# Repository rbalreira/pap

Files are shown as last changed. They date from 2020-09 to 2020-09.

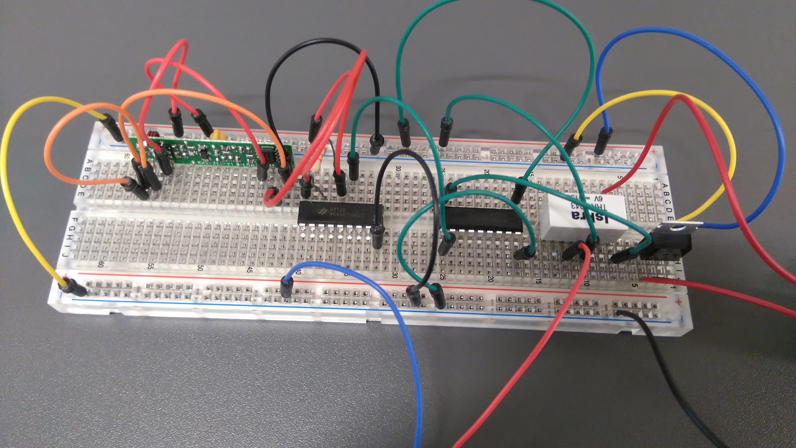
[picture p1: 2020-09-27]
assembly_pictures/receiver_14.JPG

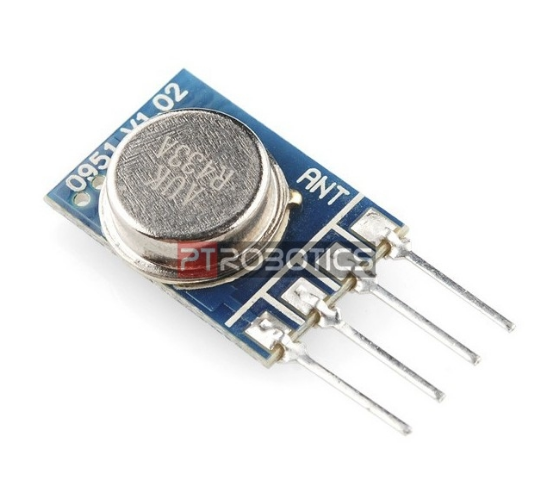
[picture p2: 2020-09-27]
components/RF transmitter.PNG

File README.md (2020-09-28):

# Prova de Aptidão Profissional
Projeto no âmbito da Prova de Aptidão Profissional do curso Técnico de Gestão de Equipamentos Informáticos do Ensino Secundário Profissional, da [Escola Secundária Marques Castilho](https://www.esmcastilho.pt/).

## Objetivo
Criação de um protótipo de pulseira electrónica conectada à campainha de uma porta de residência, permitindo que sempre que a campainha toca, um sinal é emitido para a pulseira, indicando ao portador da mesma que está alguém à porta. Com a ajuda da transmissão de radiofrequência, há ligação entre a pulseira (emissor) e a campainha (recetor). A pulseira tem um motor capaz de vibrar que indica à pessoa quando está alguém a tocar à campainha.

## Concurso Ciência na Escola
Destaque no concurso Ciência da Escola promovido pela Fundação Ilídio Pinho.

## Tecnologias
- [Fritzing](https://fritzing.org/)
- [Blender](https://www.blender.org/)

## Componentes
- RF Transmitter - 3
- RF Receiver - 2
- RF Encoder - 3
- RF Decoder - 2
- Botão de Pressão - 2
- Resistência de 750k - 4
- ULN2803 Circuito Integrado - 3
- Resistência de 33k - 4
- Motor de vibração - 3
- Buzzer - 2

## Instalação
1. Importar o projeto [assembly.fzz](assembly.fzz) no Fritzing.
2. Abrir o ficheiro [bracelet_3d.stl](bracelet_3d.stl).

## Documentação
- [Componentes usados](components)
- [Simulação do circuito](assembly.fzz)
- [Fotografias do circuito final](assembly_pictures)
- [Desenho 3D da pulseira](bracelet_3d.stl)
- [Concurso Ciência na Escola](Ciencia_na_Escola_Project/report.pdf)
- [Relatório](report.pdf)

## Autores
- Andriy Horshynskyy
- Ricardo Balreira

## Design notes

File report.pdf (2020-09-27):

IMSQUA00805

## Escola Secundária Marques de Castilho

## Técnico de Gestão de Equipamentos Informáticos

# BraceletMe

## Ricardo Balreira

## Águeda, 2017

IMSQUA00805 | i

### Índice

IMSQUA00805 | Página ii

### Índice de figuras

Fig. 3 - Placa USB (esquerda), Placa RGB LED/Botão (centro), Placa Principal

IMSQUA00805 | Página iii

IMSQUA00805 | Página iv

### Índice de quadros

IMSQUA00805 | Página v

### Resumo

Este trabalho visa explorar mecanismos que permitem a transmissão de

sinal de radiofrequência, possibilitando a interação entre uma campainha (emissor)

e uma pulseira (recetor), com recurso ao processo de comunicação com ondas de

radiofrequência, que reúne um conjunto de características ideais para o

funcionamento do mecanismo e por outro lado permite a comunicação a grandes

distâncias.

O projeto “BraceletMe” consiste na criação de um protótipo de pulseira

electrónica conectada à campainha de uma porta de residência, permitindo que

sempre que a campainha toca, um sinal é emitido para a pulseira, indicando ao

portador da pulseira que está alguém à porta. Com ajuda da transmissão de

radiofrequência vai ser possível criar uma ligação entre a pulseira (emissor) e a

campainha (recetor). A pulseira tem um motor capaz de vibrar que indica à pessoa

quando está alguém a tocar à campainha.

Palavras-chave

BraceletMe, Pulseira, Campainha, Radiofrequência.

IMSQUA00805 | 1

### 1. Introdução

No âmbito da Prova de Aptidão Profissional, foi proposto elaborar um projeto

ou atividade onde predominasse essencialmente conceitos teóricos e práticos

relacionados com a eletrónica ou com a gestão de equipamentos informáticos. A

professora responsável pela orientação do projecto foi a professora Nazaré Freitas

embora tenha sido coadjuvada pelas outras professoras da componente técnica. O

projeto teria de ser inovador, não existindo no mercado, ou introduzir qualquer

melhoria ou nova funcionalidade num produto já existente.

Apesar do constante avanço tecnológico e das diversas ideias que já foram

pensadas e postas em prática, ainda é possível dar asas à criatividade e

desenvolver um projeto inovador que surpreenda o próprio consumidor, podendo

beneficiar bastante o quotidiano do utilizador. A capacidade de poder criar algo

novo desperta a curiosidade e interesse no público e nas próprias empresas

capazes de expandir o próprio produto, o que pode ser uma mais-valia para o

criador pois vê que o seu trabalho foi reconhecido e poderá tirar grande partido da

ideia, financeiramente, pois tal como disse Flávio Souza devemos chamar o sucesso

para fazer parte [das nossas] vidas. Devemos desenvolver potencial criador, ser

inovadores, treinar a mente para vencer, estipular metas e, principalmente lutar

pelos nossos ideais.

O projeto tem como designação “BraceletMe” e foi inspirado num debate

entre algumas pessoas amigas, em que se discutiam problemas relacionados com

mobilidade nos passeios de carrinhos de bebés e pessoas portadoras de deficiência

motora. Este debate levou-nos a pensar que tipo de protótipo poderia ser

desenvolvido para ajudar as pessoas com limitações de mobilidade, ou outras. Por

outro lado, aprofundámos a nossa pesquisa com recurso à PORDATA, tentando

averiguar a percentagem de pessoas em Portugal portadoras de deficiência, e constatámos que em algumas regiões do país (Águeda, Albufeira, Porto, Lisboa,

Funchal…), a população com deficiência auditiva e visual cresceu significativamente

em 40 anos (1960-2001). Por isso, considerámos importante contribuir para a

qualidade de vida destas pessoas, lutando por um mundo melhor.

IMSQUA00805 | Página 2

O projeto “BraceletMe” consiste na criação de uma pulseira eletrónica que

emite vibração quando a campainha da porta de casa toca, indicando ao portador

que se encontra alguém à porta. O projeto parte da consciência de poder contribuir

para a solução de alguns problemas do quotidiano das pessoas portadoras de

deficiência auditiva e é movido por motivações solidárias. Além disso, poderá ainda

ter bastante utilidade no caso de pessoas com limitações inerentes à idade

avançada. A ideia surgiu também no facto de existir um familiar próximo com

problemas de audição, o que facilita assim a dificuldade em não conseguir ouvir o

toque da campainha.
Este relatório vai descrever o processo de conceção da pulseira. É

constituído por uma parte de desenvolvimento onde estará referido: o material

utilizado, maiores dificuldades na elaboração e pesquisa no projeto, vantagens e

desvantagens, fontes que foram utilizadas de forma a tornar o trabalho mais

credível, passos realizados, características dos componentes utilizados, entre

outros…; e por uma conclusão: onde haverá a oportunidade de referir a opinião

pessoal sobre o trabalho, adversidades surgidas e aspetos mais conseguidos.

### 2. Projeto “BraceletMe”

### 2.1. Esquema funcional do projeto “BraceletMe”

A imagem seguinte explica esquematicamente o objetivo do trabalho:

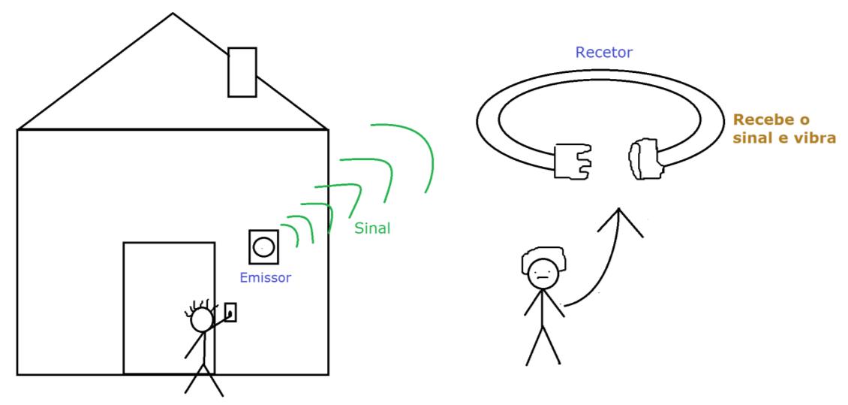
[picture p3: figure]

Fig. 1 - Esquema funcional do projeto

Como é possível observar na Fig. 1, o indivíduo que se encontra à entrada

da porta toca à campainha e, desta forma, emite um sinal para a pulseira

acionando o modo de vibração e indicando que está alguém à porta.

O projeto foi concebido para pessoas portadoras de deficiência auditiva e

para pessoas idosas, apesar de também poder ser utilizado por qualquer outro

individuo, pois também pode servir para facilitar o quotidiano de qualquer pessoa.

### 2.2. Primeira abordagem à base do projeto

Inicialmente, o protótipo a desenvolver estava em torno da utilização de um

mecanismo que permitisse a interação entre o emissor e o recetor através de

Bluetooth, o que possibilitava a transmissão de sinal sem fios. O dispositivo a ser

implementado tinha como designação de Rfduino, cuja capacidade é poder

comunicar à distância, ideal para o funcionamento do projeto. Com ótimas

características, o Rfduino pode ser alimentado por uma tensão operacional de

apenas 3V. Tem pequenas dimensões, é adaptável à pulseira e à própria campainha

e constituído por três placas (a placa principal, placa programável com entrada USB

e placa RGB LED/Botão).

São funcionalidades básicas deste dispositivo:

- Tamanho: 15 x 15 x 3.5 mm
- Tensão Operacional: 3V (Máx: 3.6V, Mín: 1.8V)
- Corrente transmitida/recebida: 8-16mA
- Processador ARM Cortex M0¹
(funcionando a 16MHz)
- 24KB de RAM
- Desenvolvido para iPhone e Android sem precisar de Xcode ou de

Android SDK (Softwares integrados para criação de aplicações)

- Bluetooth 4.0 Low Energy

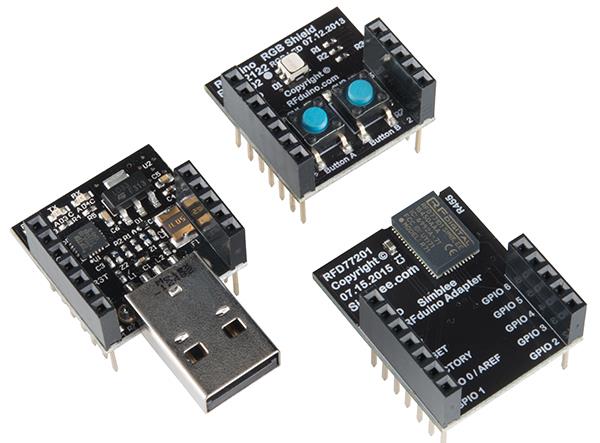
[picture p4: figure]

Fig. 2 - Equipamento Rfduino

1 Processador mais pequeno concebido pela ARM (empresa britânica de microprocessadores), com um

mínimo de requisitos de energia.

Fig. 3 - Placa USB (esquerda), Placa RGB LED/Botão (centro), Placa Principal (direita)

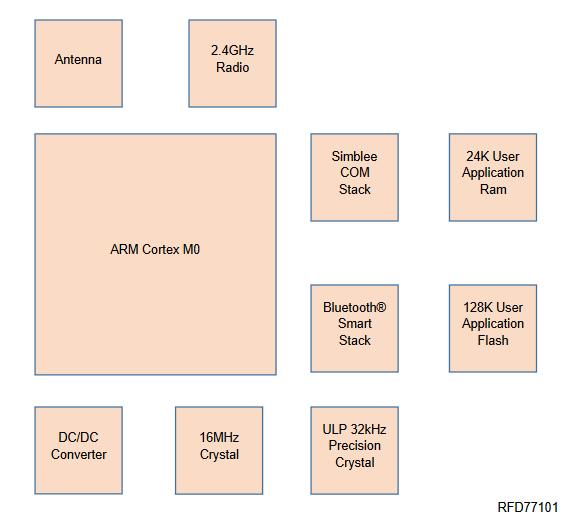
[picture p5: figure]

Fig. 4 - Diagrama de blocos, com a respetiva relação

A primeira abordagem à base do projeto consistia, portanto, em incorporar

dois microcontroladores Rfduino que pudessem comunicar entre si. Para que

houvesse a receção e passagem do sinal, teria que existir um microfone dentro do

circuito.

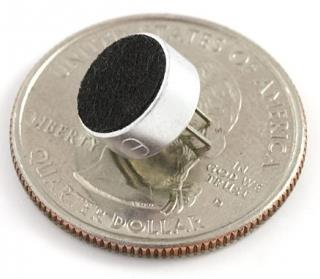
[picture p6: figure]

Fig. 5 - Microfone a ser adquirido pela Proto-Pic (loja online britânica)

No que respeita ao componente responsável por emitir sinal na pulseira, o

elemento que iria assumir essa função seria o motor de vibração.

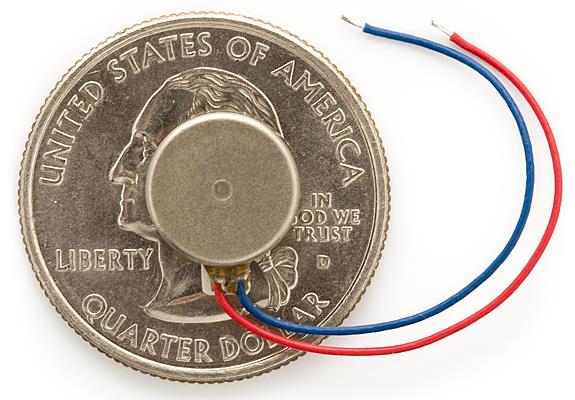
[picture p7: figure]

Fig. 6 - Motor de vibração da Sparkfun, loja online norte-americana

Depois de termos uma noção dos elementos a utilizar no projeto,

prosseguimos para a etapa seguinte, que consistia em procurar e pesquisar formas

de instalar cada componente nas condições descritas anteriormente. Através dos

esquemas elétricos de ambos os componentes e do Rfduino, procurámos conhecer

o esquema do funcionamento de uma campainha, de forma a determinar maneiras

de instalar a estrutura do Rfduino e do microfone na campainha, uma vez que o

motor de vibração irá estar na pulseira.

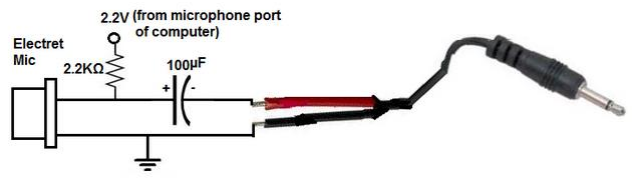
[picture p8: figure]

Fig. 7 - Circuito do microfone

Como mostra a fig. 7, para montar um microfone do tipo eletreto (cuja

finalidade é servir de escuta) vai ser preciso utilizar uma resistência de 2.2KΩ e um

condensador eletrolítico de 100µF. Como também será necessário interligar a uma

ficha de áudio e assim conectar a um computador ou a uma coluna, chegámos à

conclusão que não era, de certo modo, vantajoso optar por este elemento, dado

que este circuito exigia demasiada complexidade, segundo os tutoriais vídeo que

demonstravam, passo a passo, a montagem.

Partindo do pressuposto que a nossa “BraceletMe” estaria conectada a uma

campainha de residência (Fig. 8), estudámos o esquema elétrico respetivo.

Procedemos também ao desenho do esquema do microfone no programa “Fritzing”

para nos auxiliar na montagem do protótipo (Fig. 9). Por outro lado, pesquisámos

um esquema elétrico que possibilitasse a vibração da pulseira através de um motor

de vibração (Fig. 10) e complementámo-lo com outro esquema no programa

“Fritzing” (Fig. 11) de modo a poder recriar essa funcionalidade no protótipo.

Finalmente, a fig. 12 ilustra a junção das duas componentes: o emissor (esquema

do microfone) e o recetor (esquema do motor de vibração).

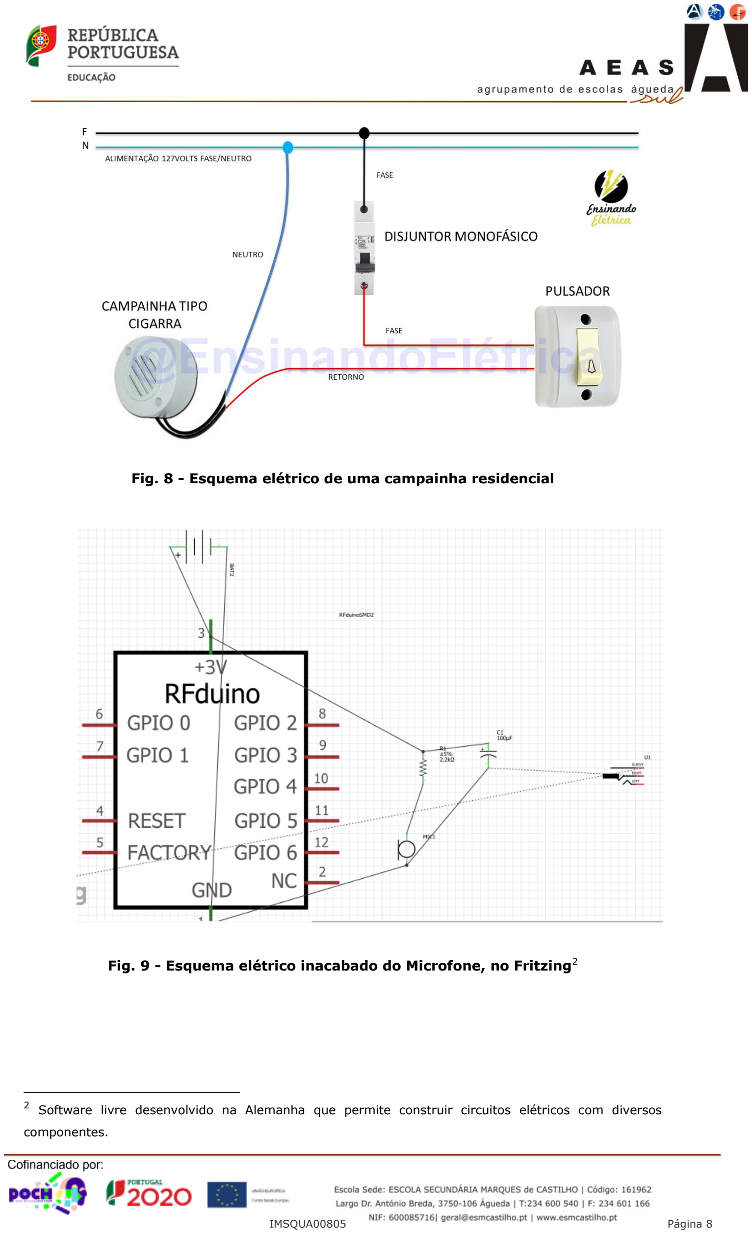
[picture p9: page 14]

Fig. 8 - Esquema elétrico de uma campainha residencial

Fig. 9 - Esquema elétrico inacabado do Microfone, no Fritzing²

2 Software livre desenvolvido na Alemanha que permite construir circuitos elétricos com diversos

componentes.

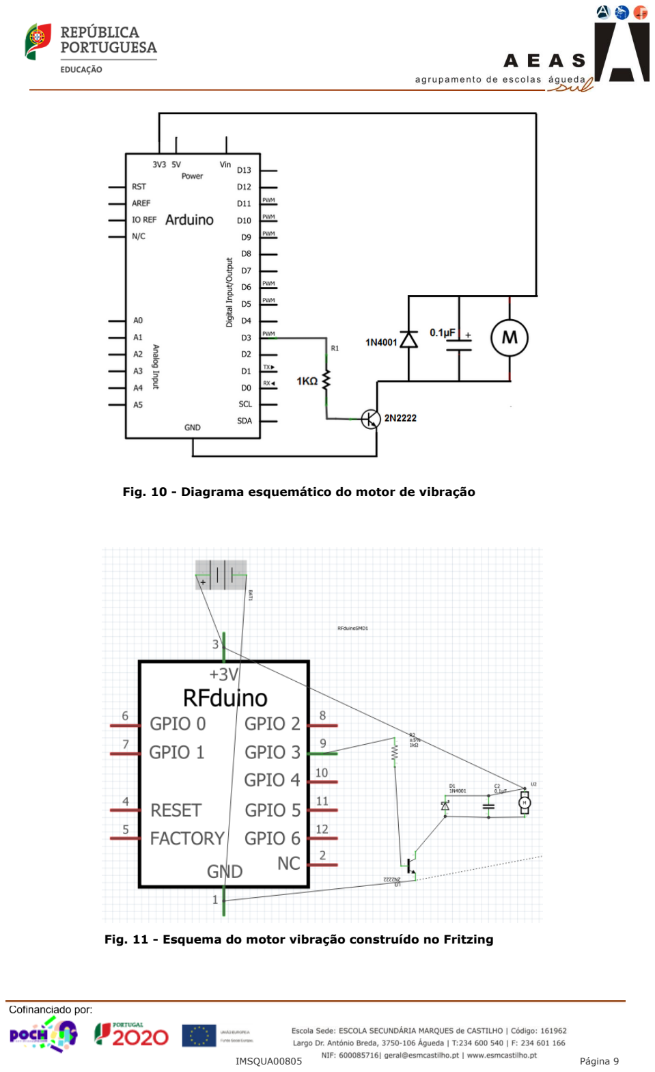
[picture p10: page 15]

Fig. 10 - Diagrama esquemático do motor de vibração

Fig. 11 - Esquema do motor vibração construído no Fritzing

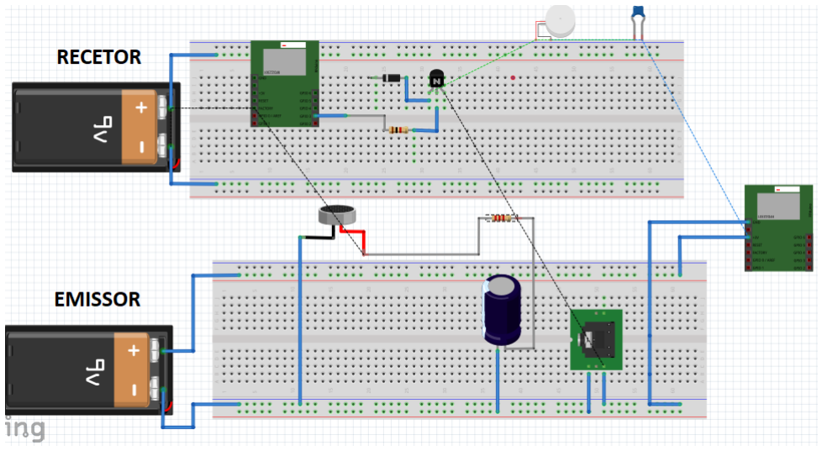
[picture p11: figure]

Fig. 12 - Esboço da primeira base do projeto montado no Fritzing

De modo a possibilitar a simulação do circuito, sem ter que recorrer a uma

campainha de uma casa, surgiu a hipótese de utilizar uma componente que

emitisse um som semelhante a uma campainha. Foi utilizado, então, um buzzer

(Fig. 14), dispositivo que envia sinal sonoro, para substituir a função da campainha.

Seguindo alguns tutoriais, operacionalizou-se a simulação, no Fritzing, do buzzer e

outros elementos necessários, como o botão de pressão, o motor de vibração, a

resistência de 330Ω, a pilha de 9V e a breadboard, tal como mostra a fig. 13.

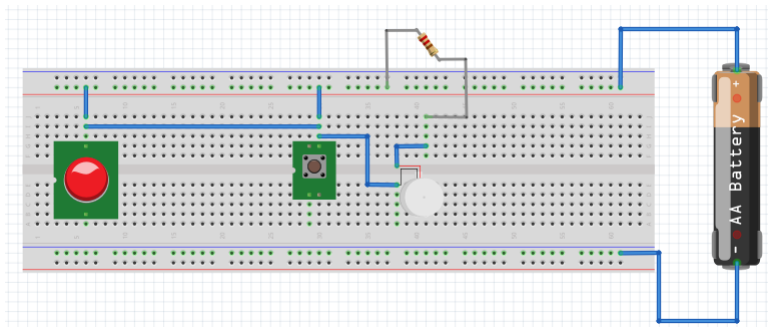
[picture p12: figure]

Fig. 13 - Simulação do motor de vibração e buzzer

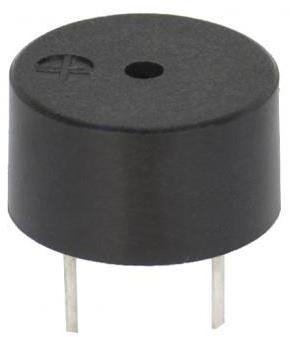
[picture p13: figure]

Fig. 14 - Exemplo de um buzzer

Na fig. 13, o buzzer está ligado ao botão de pressão e este está ligado ao

motor de vibração, com uma resistência ligada ao terminal positivo. Desta forma,

assim que é pressionado o botão de pressão, o buzzer e o motor de vibração são

ativados.

No entanto, após algumas pesquisas e discussão entre a professora

orientadora e os orientandos, inferiu-se que não era possível continuar com este

método de resolução do problema, uma vez que dois Rfduinos não conseguem

interagir um com o outro. O Rfduino foi apenas desenvolvido para comunicar com

tablet ou telemóvel (Fig. 15).

Fig. 15 - Esquema que mostra as funcionalidades do Rfduino

No fórum online do Rfduino, onde diversas pessoas podem esclarecer

dúvidas com especialistas, o administrador afirmou que não é possível interligar um

com o outro, referindo que este tipo de microcontrolador é um periférico, apenas

utilizado para dispositivos móveis que utilizam Bluetooth; no entanto, ele diz ainda

que outras funcionalidades estão a ser desenvolvidas, estando em estudo a

utilização de mecanismos de radiofrequência (emissor – recetor) – RF library – sem

ter que recorrer a via Bluetooth.

Assim, procurámos outros procedimentos e soluções para resolver esta

questão. Surgiu a ideia de utilizar o mesmo mecanismo usado nos automóveis para

o controlo remoto.

### 2.3. Nova abordagem ao esquema funcional do projeto

Decidimo-nos por uma solução bastante eficaz e simples que permite a

comunicação à distância. Essa solução consistia em utilizar um transmissor e um

recetor comunicando através de radiofrequência (RF). A imagem (Fig. 16) mostra a

fonte de onde nos inspirámos para desenvolver uma nova abordagem.

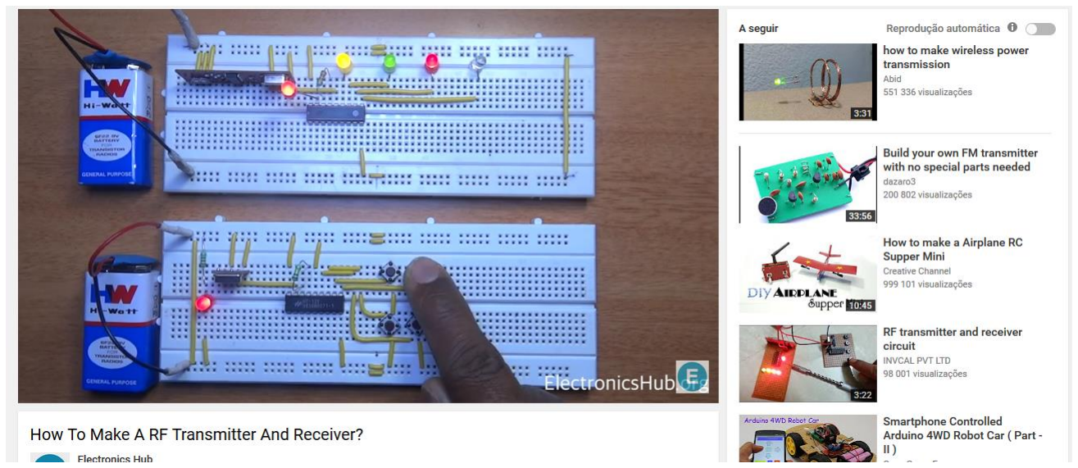
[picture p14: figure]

Fig. 16 - Vídeo que explica como utilizar um transmissor e recetor a RF

Esta técnica consiste em utilizar o módulo RF (“transmitter” e “receiver”) e

dois RF “encoder” e “decoder”, sendo os elementos principais da montagem. Cada

componente tem a sua função que passaremos a descrever:

- RF transmitter – componente eletrónico que recebe dados em série e

transmite-os, sem necessitar de conexão de fios, através da sua antena

conectada no pino 4.

- RF receiver – os dados transmitidos são recebidos por este componente

que opera à mesma frequência que o RF transmitter.

- RF encoder e decoder - utilizam-se na ligação de controlo remoto RF,

assegurando e tornando mais fiável essa mesma ligação, sendo bastante

fácil incorporá-los no RF module (módulo RF), sendo facilmente

integrados. Tal como os nomes indicam, encoder e decoder significam

“codificar” e “descodificar”, respetivamente.

Como o autor do vídeo utilizou o circuito para outra finalidade – ligar vários

díodos LED alternadamente – foi preciso estudar o circuito, cada componente e

consultando o datasheet de cada componente (ficha técnica) e a ligação dos

terminais e pinos, de forma a retirar os LED e substitui-los pelo buzzer e motor de

vibração, deixando apenas um botão de pressão no emissor.

### 2.4. Método do circuito final

Encontrada a solução para assegurar a funcionalidade do esquema do nosso

projeto, procedemos à aquisição das duas componentes essenciais: RF transmitter

e o RF receiver que passaremos a descrever em pormenor o modo de

funcionamento e de ligação.

### 2.4.1 Descrição dos componentes

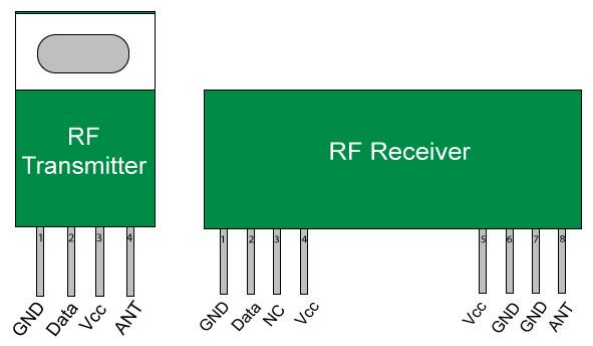
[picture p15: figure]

Fig. 17 - Identificação dos pinos do módulo RF

Nas tabelas seguintes é feita a descrição de cada pino do RF module:

Quadro 1 – RF transmitter

Número do Pino | Função | Nome
1 | Terra (0V) | GND (Terra)
2 | Pino de entrada dos dados em série | Dados
3 | Fornecedor de energia (5V) | Vcc
4 | Antena, pino de saída | ANT (Antena)

Quadro 2 – RF receiver

Número do Pino | Função | Nome
1 | Terra (0V) | GND (Terra)
2 | Pino de entrada dos dados em série | Dados
3 | Pino de saída linear (não conectado) | NC (Não Conectado)
4 | Fornecedor de energia (5V) | Vcc
5 | Fornecedor de energia (5V) | Vcc
6 | Terra (0V) | Terra
7 | Terra (0V) | Terra
8 | Antena, pino de saída | ANT (Antena)

Do RF transmitter faz parte a componente Encoder que tem as seguintes

caraterísticas:

- Tensão Operacional:
- 2.4V ~ 5V HT12A
- 2.4V ~ 12V HT12E
- Baixa Energia e Elevada Imunidade de Ruído Tecnologia CMOS³
- HT12A com um transportador de 38kHz para a transmissão de infravermelho

médio

- Mínima Transmissão de Palavra:
- Quatro Palavras (Words) HT12E
- Uma Palavra HT12A
- Oscilador integrado que necessita apenas de 5% de resistência
- O código de dados tem polaridade positiva
- Componentes Externos Mínimos
- HT12A/E: 18 pinos DIP⁴
(Dual In-Line Package) / 20 pinos SOP (Small

Outline Package)

3 CMOS – “Complementary Metal Oxide Semiconductor”. Pequena área de memória volátil, alimentada

por uma bateria.
4 Chip revestido por um plástico duro com pinos a percorrer ao longo do exterior.

O encoder pode ser aplicado em contextos vários como esclarece o quadro 3.

Quadro 3 – Aplicações do encoder

Sistema de alarme antirroubo | Sistema de alarme de incêndio e detetor de fumo
Controladores de porta de garagem | Controladores de portas de carros
Sistema carro de alarme | Sistema de segurança
Telefones sem fios | Outros sistemas de controlo remoto

O encoder obedece a um esquema específico de pinos (Fig. 18) que é

necessário ter em conta para estabelecer a ligação entre este componente e outros,

como por exemplo, botão de pressão, resistência e buzzer, tal como é ilustrado na

Fig. 27, mais à frente neste relatório.

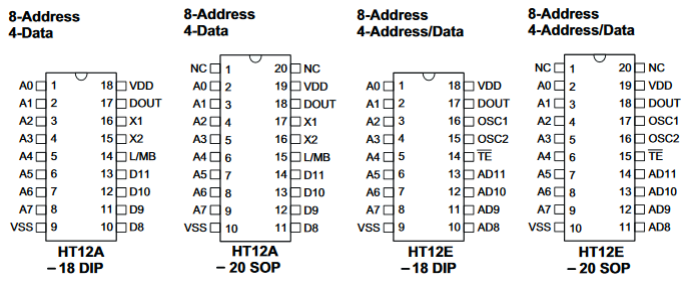
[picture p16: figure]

Fig. 18 - Esquema elétrico do RF encoder (HT12A e HT12E)

De seguida apresentamos uma tabela pormenorizada com a descrição das

características dos pinos do encoder a utilizar neste projeto.

Quadro 4 – Descrição dos pinos

Pino (designação) | I/O | Conexão Interna | Descrição
A0~A7 | I | CMOS IN Pull-High (HT12A) | Pinos de entrada para endereçarem a configuração de A0~A7. Estes pinos podem ser definidos externamente para o VSS ou podem ficar em aberto.

NMOS

Transmissão

Pino (designação) | I/O | Conexão Interna | Descrição
| | de Porta Proteção de Díodo (HT12E)
AD8~AD11 | I | NMOS Transmissão de Porta Proteção de Díodo (HT12E) | Pinos de entrada para endereçarem/dados da/a configuração de AD8~AD11. Estes pinos podem ser definidos externamente para o VSS ou podem ficar em aberto.
D8~D11 | I | CMOS IN Pull-High | Pinos de entrada para configuração e transmissão de dados de D8~D11 permitidas, baixa ativação (ver nota) Estes pinos devem ser definidos externamente para o VSS ou devem ficar em aberto
DOUT | O | CMOS OUT | Transmissão dos dados em série do codificador
L/MB | I | CMOS IN Pull-High | Transmissão do formato de seleção do pino de trinco/momentânea: Trinco: Flutuador ou VDD Momentâneo: VSS
TE | I | CMOS IN Pull-High | Permissão da transmissão, baixa ativação (ver Nota)
OSC1 | I | Oscilador 1 | Pino de entrada do oscilador
OSC2 | O | Oscilador 1 | Pino de saída do oscilador
X1 | I | Oscilador 2 | Entrada do ressonador de 455kHz no oscilador
X2 | O | Oscilador 2 | Saída do ressonador de 455kHz no oscilador
VSS | I | - | Fornecimento de energia negativa, terra
VDD | I | - | Fornecimento de energia positiva

Nota: D8~D11 são todas entradas de dados e pinos com capacidade de transmissão do HT12A. TE é um

pino com capacidade de transmissão do HT12E.

Tal | como fizemos para | o encoder, apresentamos de seguida | as

características do decoder:

- Tensão Operacional: 2.4V – 12V
- Baixa Energia e Elevada Imunidade de Ruído Tecnologia CMOS
- Capaz de descodificar 12 bits de informação
- Configuração do endereço binário
- Códigos recebidos são verificados 3 vezes

- Combinação do número de endereço/dados
- HT12D: 8 bits de endereços e 4 bits de dados
- HT12F: Apenas 12 bits de endereços
- Oscilador integrado que necessita apenas de 5% de resistência
- Indicador de transmissão válido
- Fácil Interface com um RF ou uma transmissão infravermelha média
- Componentes Externos Mínimos
- Dupla com 2¹² séries de codificadores Holtek’s⁵
- 18 Pinos DIP, 20 Pinos de pacotes SOP

Também o decoder pode ser aplicado em contextos vários como esclarece o

quadro 5.

Quadro 5 – Aplicações do decoder

Sistema de alarme antirroubo | Sistema de alarme de incêndio e detetor de fumo
Controladores de porta de garagem | Controladores de portas de carros
Sistema carro de alarme | Sistema de segurança
Telefones sem fios | Outros sistemas de controlo remoto

O decoder também obedece a um esquema específico de pinos (Fig. 19) que

é necessário ter em conta para estabelecer a ligação entre este componente e

outros, como por exemplo, motor de vibração, resistência e relé, tal como é

ilustrado na Fig. 28, mais à frente neste relatório.

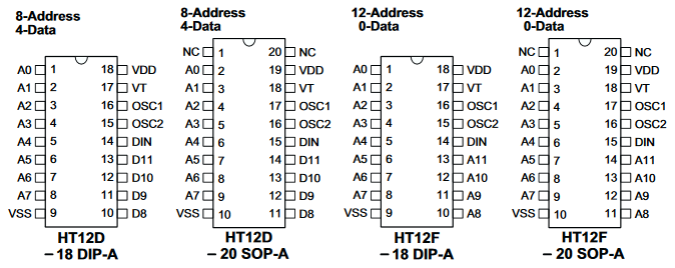
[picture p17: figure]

Fig. 19 - Esquema elétrico do RF decoder (HT12D e HT12F)

5 Empresa chinesa que produz semicondutores.

De seguida, também apresentamos uma tabela pormenorizada com a

descrição das características dos pinos do decoder a utilizar neste projeto.

Quadro 6 – Descrição dos pinos

Pino (designação) | I/O | Conexão Interna | Descrição
A0~A11 (HT12F) | I | NMOS Porta de Transmissão | Pinos de entrada para endereçarem a configuração de A0~A11 Estes pinos podem ser definidos externamente para o VSS ou podem ficar em aberto
A0~A7 (HT12D) | | | Pinos de entrada para endereçarem a configuração de A0~A7 Estes pinos podem ser definidos externamente para o VSS ou podem ficar em aberto
D8~D11 (HT12D) | O | CMOS OUT | Pino de entrada de dados, estado de energia é baixo
DIN | I | CMOS IN | Pino de entrada de dados em série
VT | O | CMOS OUT | Transmissão válida, elevada
OSC1 | I | Oscilador | Pino de entrada do oscilador
OSC2 | O | Oscilador | Pino de saída do oscilador
VSS | - | - | Fornecimento de energia negativa, terra
VDD | - | - | Fornecimento de energia positiva

A fig. 20 demonstra um dos ensaios de composição dos elementos

eletrónicos que serviria de base ao “BraceletMe”, onde se veem dois circuitos: o

transmissor, responsável por enviar o sinal para o RF receiver, está ligado ao RF

encoder que, por sua vez, está conectado ao buzzer, ao botão de pressão e à

resistência. O recetor, neste caso o RF receiver recebe o sinal vindo do RF

transmitter que está ligado ao RF decoder que estabelece a ligação com o motor de

vibração e a resistência. Assim que o RF receiver recebe o sinal o motor de vibração

é ativado.

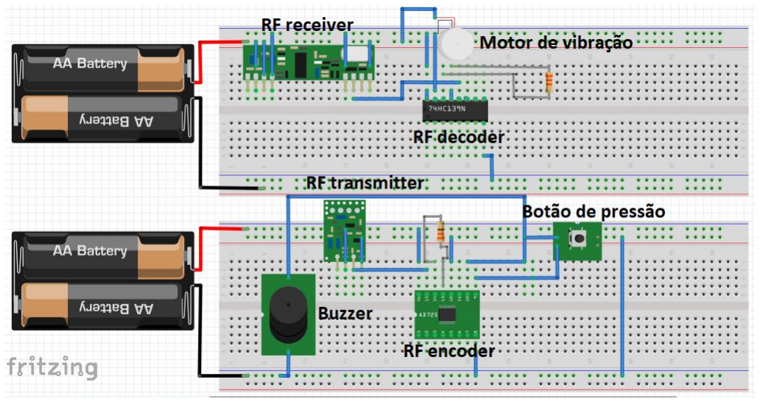
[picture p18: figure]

Fig. 20 - Esquema do método a desenvolver

Neste sistema RF, o sinal é modulado pelo que se designa por Amplitude

Shift Keying (ASK) – Deslocamento da Amplitude. Neste género de modulação, o

sinal digital sofre uma variação na sua amplitude dando origem a um sinal

analógico. Tudo isto ocorre na transmissão de ondas eletromagnéticas (Fig. 21).

Os esquemas abaixo são apenas desenhos ou esboços, pelo que servem

apenas para ver os primeiros passos na construção dos dois circuitos. No entanto,

já é possível ver como o esquema irá funcionar: o botão de pressão é pressionado e

é enviado um sinal para o RF transmitter, que depois transmite a informação para o

outro circuito, sendo recebido pelo RF receiver. O buzzer é acionado assim que

recebe corrente vindo da fonte de alimentação com a ativação do botão. Assim que

o sinal é recebido pelo RF receiver, este liga o motor de vibração (Fig. 22 - 23). O

LED do esquema do recetor foi utilizado para termos a certeza se passa ou não

corrente no circuito.

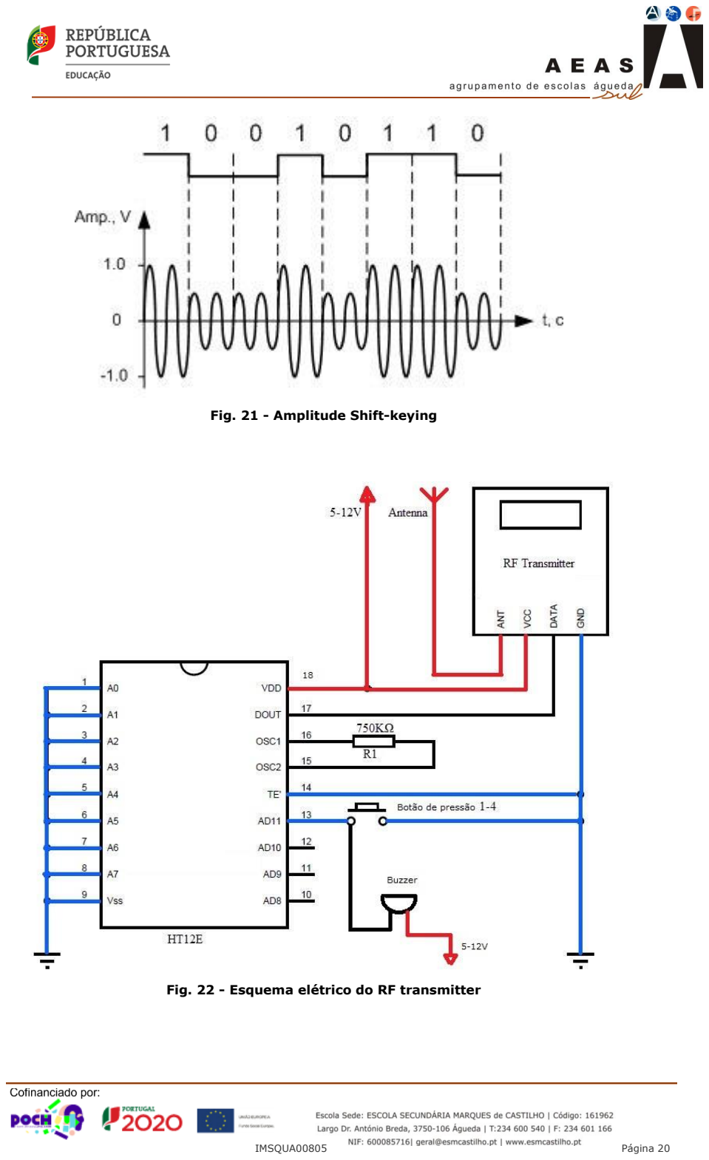
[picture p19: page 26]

Fig. 21 - Amplitude Shift-keying

Fig. 22 - Esquema elétrico do RF transmitter

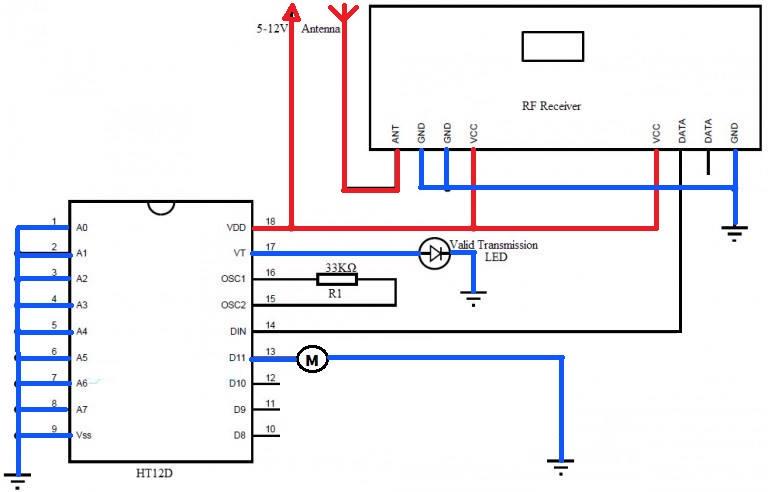
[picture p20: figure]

Fig. 23 - Esquema elétrico do RF receiver Definidos os elementos a utilizar, prosseguimos então para a etapa seguinte

que consistia em pedir o material para assim construir o protótipo. Durante o

período de montagem do circuito surgiram alguns contratempos. A ligação dos

componentes e o facto do motor de vibração estar acionado constantemente, sem

sequer existir um mecanismo que o ligasse e desligasse, foi um dos aspetos a

corrigir nesta fase.

Após a ligação entre os circuitos estar a funcionar, foi preciso optar por uma

alternativa que ligasse e desligasse o motor de vibração e buzzer consoante o

pressionar do botão de pressão. Essa alternativa consistiu em utilizar um

componente denominado de relay (relé). O relay é um componente eletromecânico

que permite ligar, desligar e comutar (desviar) um sinal, ou seja, é constituído por

um mecanismo que bloqueia, desbloqueia e muda de direção o sinal percorrido. Tal

como podemos ver na fig. 24, um relé é composto por uma bobina, uma armadura

móvel que “abre” e “fecha” e por um grupo de contactos.

Fig. 24 - Estrutura do relé

Quando essa bobina recebe corrente elétrica cria-se um campo magnético

que atua sobre a armadura, atraindo-a. Assim que essa corrente deixa de circular

pela bobina, o campo magnético desaparece fazendo com que a armadura móvel

volte à sua posição inicial. Nesta atração ocorre um movimento que ativa os

contatos, os quais podem ser abertos, fechados ou permutados, dependendo da

sua posição (Fig. 25).

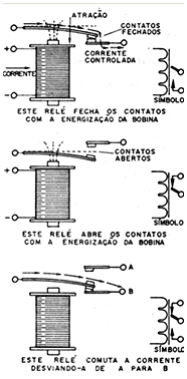
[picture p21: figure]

Fig. 25 – Funcionamento do relé

Podemos controlar circuitos de tensões bastante altas como 110V ou 120V

com um relay cuja bobina é alimentada com apenas 6V ou 12V, não

comprometendo o seu funcionamento. Consoante o seu tipo de aplicação, um relé

pode ter um ou vários contactos que podem ser designados por Normalmente

Fechado (NF), Normalmente Aberto (NA) e Contacto Comum. Os contactos podem

ter a seguinte combinação: NA, NF, NA+NF+C. Os contactos NA estão isolados

quando não existe passagem de energia; assim que há passagem de corrente, os

contactos fecham e há continuação da circulação de energia para acionar uma

carga externa (por exemplo: motor ou lâmpada). No caso dos contactos NF, a

situação é quase idêntica. A única diferença é que estes estão fechados com o relé

desativado, daí designarem-se por Normalmente Fechado. Na combinação

NA+NF+C o objetivo passa por ligar ou desligar uma das cargas quando se ativa o

relay, tendo duas cargas a alimentar. Com o relay desligado, há um contacto fechado e um segundo aberto. Quando há passagem de corrente, o relé desvia o

sinal fechando o contacto que estava aberto ficando apenas a carga 2 em

funcionamento (Fig. 26).

Fig. 26 – Funcionamento dos três tipos de relés

Para a montagem do projeto, será preciso usar um relé com quatro pinos

laterais para bloquear e desbloquear a passagem de energia. Esses quatro pinos

são formados pelos contactos NA, NF e C, tal como mostra a fig. 27. A segunda

imagem da fig. 27 é um exemplo de um tipo de relé.

Fig. 27 - Identificação dos pinos do relay a utilizar e exemplo de um relé

Imaginemos o exemplo de utilizar o motor de vibração, tal como se pretende

neste projeto. O motor de vibração está ligado ao contacto NA e, assim que ocorrer

circulação de corrente, o contacto comum desloca-se para o NA, fazendo com que o

motor receba energia e vibre.

### 2.4.2. Circuito Integrado ULN2803

No decorrer das montagens, notou-se que era preciso um microcontrolador

que permitisse conduzir a corrente até ao relé para que este ativasse e acionasse o

motor de vibração. Sem isso, não é possível a passagem de corrente até ao relé.

Neste caso foi necessário introduzir uma outra componente, circuito integrado

ULN2803, que garante a passagem de corrente (Fig. 28), onde é esquematizado os

pinos de ligação.

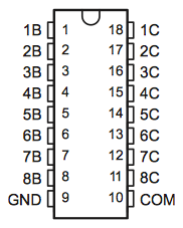
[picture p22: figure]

Fig. 28 - Identificação dos pinos do ULN2803

O quadro 7 descreve ao pormenor a tipologia e funcionalidade dos pinos do

circuito interno.

Quadro 7 – Descrição dos pinos

Pino | Tipo | Descrição
Nome | Número
1B | 1 | I | Canal 1 através da base das 8 entradas Darlington⁶
2B | 2
3B | 3

6 Transístor Darlington – é um transístor composto por dois transístores bipolares conectados onde o

segundo transístor cria uma amplificação adicional no primeiro transístor.

Pino | Tipo | Descrição
Nome | Número
4B | 4
5B | 5
6B | 6
7B | 7
8B | 8
1C | 18 | 0 | Canal 1 através do coletor das 8 saídas Darlington
2C | 17
3C | 16
4C | 15
5C | 14 | 0 | Canal 1 através do coletor das 8 saídas Darlington
6C | 13
7C | 12
8C | 11
GND | 9 | - | Emissor comum partilhado por todos os canais (típico vínculo para a terra)
COM | 10 | I/O | Nó comum do cátodo para díodos flyback (necessário para cargas indutivas)

### 2.5. Circuito Final

Introduzido o circuito ULN2803, de uma forma geral e compreensível, o

circuito global do projeto “BraceletMe” funciona da seguinte maneira:

- Assim que é pressionado o botão de pressão, é transmitida uma série de

dados onde serão verificados pelo “encoder”. Depois de este codificar a informação

recebida – com o buzzer a tocar em simultâneo – envia os dados para o RF

transmitter, e este, por sua vez, envia-os (através da sua antena) para o RF

receiver. O RF receiver envia o sinal recebido para o “decoder”, cujo papel passa

por descodificar a informação em série. Depois de esta estar devidamente

descodificada, percorre os fios condutores até ao relé, que desbloqueia logo que

esta informação é recebida. O contacto comum entra em contacto com o NA,

permitindo a circulação de corrente, o que vai possibilitar que o motor de vibração

acione, na medida em que o relé é o componente responsável por deixar percorrer

corrente até ao motor de vibração. Caso o relé não destranque, o motor de vibração não liga. Quando o botão deixa de ser pressionado, o relé volta ao ponto

inicial, isto é, fica bloqueado. Sem o circuito integrado ULN2803, não há

continuação da passagem de corrente até ao relé.

Até à fase da conclusão do circuito, foi necessário repetir várias vezes a

montagem até termos o resultado desejado, tentando corrigir os problemas de mau

contacto, falha nas ligações e falta ou excesso de passagem de corrente. Vários

problemas que surgiram ao longo do trabalho tiveram que ser analisados para

assim serem emendados. Utilizaram-se transístores para transformar a tensão da

pilha de 9V em 5V, uma vez que não tínhamos disponíveis pilhas de voltagem mais

baixa. Os transístores cingiram-se apenas para o motivo referido e para teste, em

ambos os circuitos, seguindo o seu esquema técnico de ligação (Fig. 29).

Os esquemas elétricos da fig. 30 e da fig. 31 referem-se ao circuito

concluído, com todos os elementos que foram utilizados. Concretamente, na fig. 30

(emissor), é possível ver o buzzer que está ligado ao trilho positivo da placa e ao

botão de pressão, sendo capaz de ligar e desligar o buzzer. A imagem demonstra

também o RF encoder que desempenha o papel de codificar o conjunto de dados

recebidos para depois encaminhar para o RF transmitter. A resistência de 750kΩ

opõe-se à passagem de corrente elétrica para não comprometer o funcionamento

do RF encoder. Na Fig. 30, vemos o circuito do recetor onde podemos observar o

conjunto de elementos que dele fazem parte: motor de vibração, relé, RF receiver,

RF decoder, resistência de 33kΩ e CI ULN2803. O motor de vibração está ligado ao

contacto NO (Normally Open – Normalmente Aberto) para quando o relé é acionado

possa existir passagem de energia com o contacto comum ligado ao NA. A

resistência de 33kΩ desempenha a mesma função da resistência do emissor. Para a

corrente chegar ao relé terá de passar pelo ULN2803, comprovando a sua situação

descrita anteriormente. O RF decoder recebe os dados em série do RF receiver

descodificando-os para, assim, os enviar para o ULN2803 que, por sua vez, os

transmite para o relé.

Fig. 29 - Identificação dos pinos do transístor utilizado

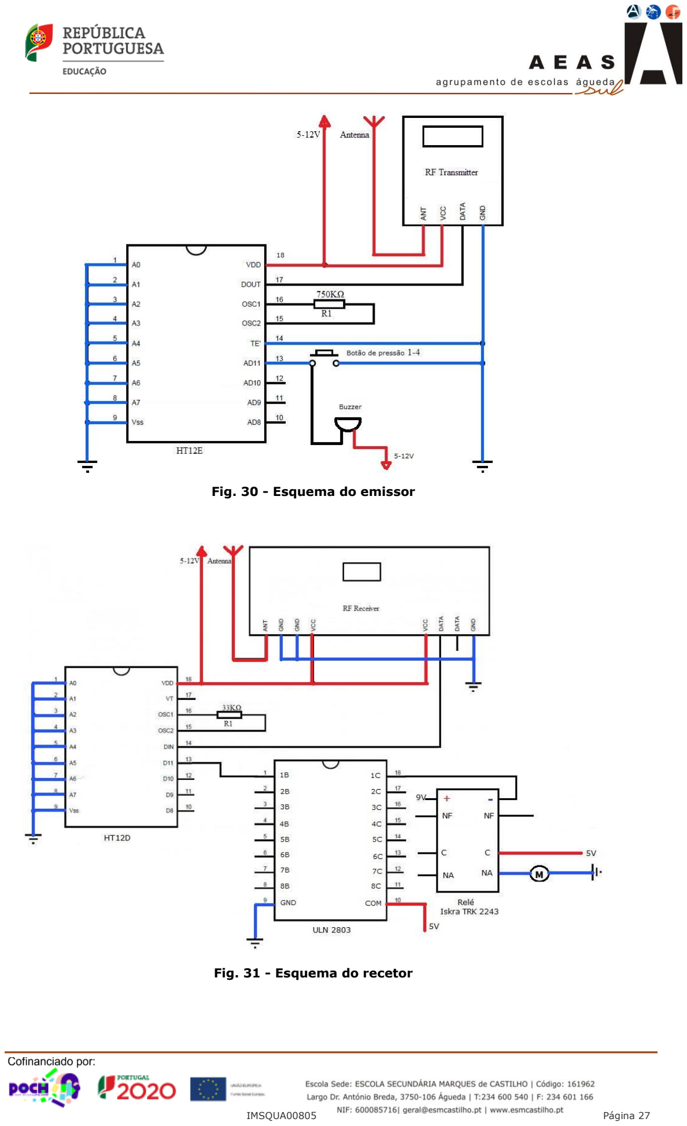
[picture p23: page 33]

Fig. 30 - Esquema do emissor

Fig. 31 - Esquema do recetor

### 2.5.1. Componentes utilizados

Os materiais utilizados na montagem do circuito foram adquiridos na

PTRobotics e na Jet7store, duas empresas portuguesas que vendem equipamento

informático. No quadro 8 estão discriminados as componentes, as suas

características e o preço de mercado. A construção do protótipo importou 55,93€.

Quadro 8 – Material Utilizado

Nome | Características | Preço
RF transmitter | ▪ Modelo PTR000875 ▪ 434 MHz ▪ 500 Metros de gama ▪ 4800bps de taxa de dados ▪ 5V tensão de alimentação | 4,61€ 3,75€ Sem IVA
RF receiver | ▪ Modelo PTR000877 ▪ 434 MHz ▪ 500 Metros de gama ▪ 4800bps de taxa de dados 5V tensão de alimentação | 5,54€ 4,50€ Sem IVA
RF encoder | ▪ Modelo PTR001199 ▪ HT12E - Codificador de controlo remoto | 3,69 € 3,00€ Sem IVA
RF decoder | ▪ Modelo PTR001199 ▪ HT12D – Descodificador de controlo remoto | 3,69 € 3,00€ Sem IVA

ULN2803 | ▪ Modelo PTR000120 | 0,80€ 0,65€ Sem IVA
2 Transístores LM7805AC | • Modelo PTR002240 • 7805 Regulador de tensão básico | 0,74€ 0,60€ Sem IVA
1 Relé | • Iskra TRK 2243 • 6V = 0136 | 2,10€ 1,71€ Sem IVA
3 Suportes de pilha 9V | - | 0,50€ 0,41€ Sem IVA

Buzzer

- Modelo PTR000607
- Resistência da bobina:

16Ω

- Corrente Máxima: 35mA
- Classificação da

Corrente: 35mA

- Diâmetro externo: 12mm
- Altura/Comprimento

externo: 8.5mm

- Frequência: 2.048kHz
- Material: PPO (Preto)
- Frequência ressonante:

2kHz

- Distância do nível do

som: 10cm

- Nível do som SPL: 85dB
- Fornecimento de tensão:

1.5V

- Fornecimento de tensão

AC Máxima: 2V

- Fornecimento de

tensão AC Mínima: 1V

- Fornecimento de

tensão Máxima: 2V

- Fornecimento de

tensão Mínima: 1V

- Peso: 1.4g

0,98 €

0,80€ Sem

IVA

Motor de vibração

- Modelo PTR002951
- Dimensões: 10mm

diâmetro, 2.7mm espessura

- Tensão: 2V – 5V
- Absorção elétrica 5V:

100mA; absorção elétrica

4V: 80mA; absorção

elétrica 3V: 60mA;

absorção elétrica 2V: 40mA

2,77€

2,25€ Sem

IVA

| ▪ 11000 Rotações p/minuto 5V ▪ Peso: 0.9 gramas
Botão de pressão | ▪ Modelo PTR001050 ▪ Botão táctil de cor preta | 0,49€ 0,40€ Sem IVA
Fios de ligação (Jumper Wires) | - | 1,85€ 1,50€ Sem IVA
2 Breadboards | - | 9,23€ 7,50€ Sem IVA
1 Resistência 33kΩ e 750kΩ | - | 0,12€ 0,10€ Sem Iva

0,29€

3 Pilhas | ▪ 9V | 2,52€ 2,05€ Sem IVA
Total (incluindo quantidade utilizada): | | 55,93€ 45,53€ Sem Iva

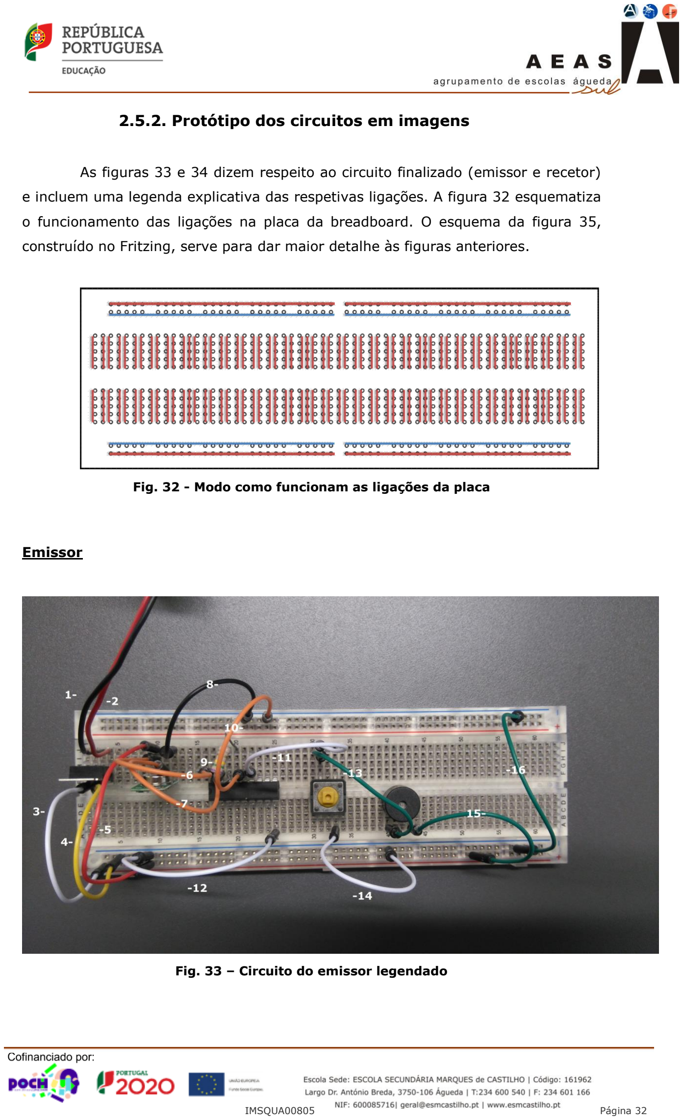
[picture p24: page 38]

### 2.5.2. Protótipo dos circuitos em imagens

As figuras 33 e 34 dizem respeito ao circuito finalizado (emissor e recetor)

e incluem uma legenda explicativa das respetivas ligações. A figura 32 esquematiza

o funcionamento das ligações na placa da breadboard. O esquema da figura 35,

construído no Fritzing, serve para dar maior detalhe às figuras anteriores.

Fig. 32 - Modo como funcionam as ligações da placa

Emissor

Fig. 33 – Circuito do emissor legendado

1 - Polo negativo da pilha (fio preto) de 9V ligado ao terminal negativo (GND) do

transístor LM7805AC.

2 - Polo positivo da pilha (fio vermelho) de 9V ligado ao terminal de entrada (Input)

do transístor LM7805AC.

3 - Fio ligado ao terminal de saída (Output) do transístor e ao trilho positivo da

breadboard.

4 - Fio ligado ao terminal Input do transístor e ao trilho negativo da breadboard.

5 - Fio que liga o pino Vcc do RF transmitter ao trilho positivo da placa breadboard.

6 - Pino Vcc do RF transmitter ligado ao pino VDD do HT12E.

7 - Pino Data do RF transmitter ligado ao pino DOUT do HT12E.

8 - Ligação do pino GND do RF transmitter ao trilho negativo da placa.

9 - Resistência de 750KΩ ligada aos pinos OSC1 e OSC2.

10 - Pino TE ligado ao trilho negativo da placa.

11 - Pino AD11 ligado a um dos terminais do botão de pressão.

12 - Pino VSS ligado ao trilho negativo da placa.

13 - Fio com ligação ao mesmo trilho do fio 11 do botão de pressão e ao terminal

negativo do buzzer.

14 - Terminal do botão de pressão ligado ao trilho negativo da placa.

15 - Ligação do terminal positivo do buzzer ao trilho positivo da placa.

16 - Interligação dos dois trilhos negativos da placa.

Recetor

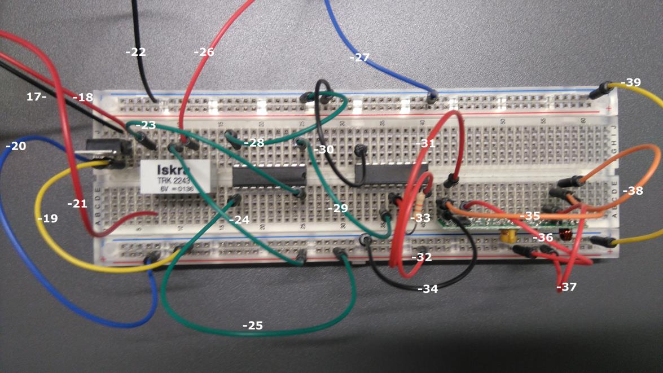
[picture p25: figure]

Fig. 34 - Circuito do recetor legendado

17 - Polo negativo da pilha de 9V ligado ao terminal negativo (GND) do transístor

LM7805AC.

18 - Polo positivo da pilha de 9V ligado ao terminal de entrada (Input) do transístor

LM7805AC.

19 - Fio ligado ao terminal GND do transístor e ao trilho negativo da breadboard.

20 - Fio ligado ao terminal Output do transístor e ao trilho positivo da placa.

21 - Ligação do polo positivo da segunda pilha ao terminal positivo do relé.

22 - Ligação do polo negativo da segunda pilha ao trilho negativo da placa.

23 - Ligação do pino 1C do ULN2803 ao terminal negativo do relé.

24 - Ligação do Contacto Comum do relé ao trilho positivo da placa (5V).

25 – Pino COM do ULN2803 está ligado ao trilho positivo da placa (5V).

26 - Ligação do terminal positivo do motor (fio vermelho) ao contacto NA do relé.

27 - Ligação do terminal negativo do motor (fio azul) ao trilho negativo da placa.

28 – Ligação do pino GND ao trilho negativo da placa.

29 - Pino 1B está ligado ao pino D11 do HT12D.

30 – Ligação do pino VSS ao trilho negativo da placa.

31 - O pino DIN do HT12D está ligado ao pino Data do RF receiver.

32 – Ligação do pino VDD ao trilho positivo da placa, ou seja, aos 5V.

33 - A resistência de 33KΩ está ligada aos pinos OSC1 e OSC2 do decoder.

34 - O pino GND do RF receiver está ligado ao trilho negativo da placa (GND).

35 – Interligação dos dois pinos GND do RF receiver.

36 – Ligação do pino VCC do RF receiver ao trilho positivo da placa breadboard.

37 – Ligação do outro pino VCC do RF receiver ao trilho positivo da placa.

38 - Interligação dos dois pinos GND do RF receiver.

39 - Interligação dos dois trilhos negativos da placa.

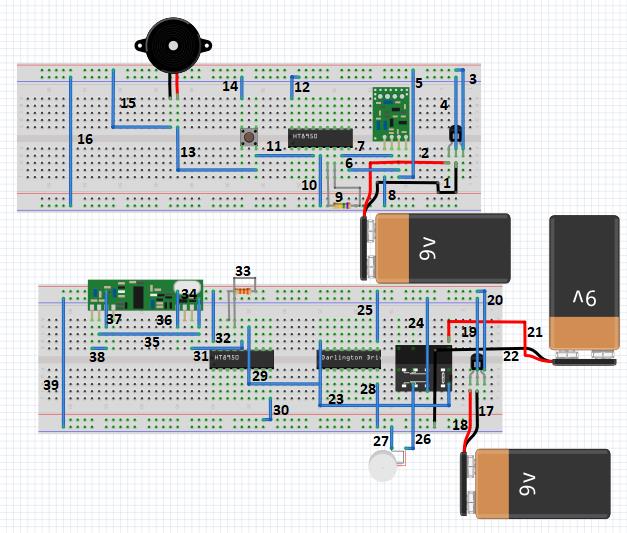
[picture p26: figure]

Fig. 35 - Esquema Fritzing com ambos os circuitos

### 3. Conclusão

Em suma, com este projeto conseguimos construir o circuito a que nos

propusemos, tendo a sua concretização correspondido às expectativas, pois foi

interessante poder criar uma pulseira recorrendo ao sistema de radiofrequência

que permite, a julgar pelos ensaios efetuados, interligar uma campainha com a

ideia de pulseira eletrónica com o objetivo de facilitar de forma simples a vida

de pessoas com dificuldades auditivas ou que, pela idade avançada, tenham

outro tipo de dificuldade sensoriais.

No âmbito teórico e prático, o projeto foi concebido com maior domínio na

área da eletrónica. Todos os elementos e conceitos usados e aplicados,

respetivamente, estiveram mais relacionados com a montagem de circuitos,

teste dos componentes, procura das fichas técnicas (datasheets), estudo da

melhor forma de realizar o projeto, e, o mais importante, com o

desenvolvimento de competências na resolução de problemas. A realização

deste tipo de trabalhos pretende procurar o lado autónomo e de autossuperação

por parte do aluno, sendo uma mais-valia para o mundo do trabalho.

Ao longo do projeto, tal como já fora referido no relatório, surgiram algumas

dificuldades, | nomeadamente | o | processo | de | testagem-erro-reformulação

permanente até ao protótipo final ficar funcional. A maior dificuldade

encontrada foi o facto de se descobrir que dois microcontroladores Rfduino não

podem ser utilizados em simultâneo porque não são compatíveis. Esta situação

afetou parcialmente o ritmo do trabalho, pois foi preciso procurar uma nova

solução rapidamente para não comprometer o desenvolvimento e a conclusão

do projeto. No entanto, o método RF Receiver e RF Transmitter provou ser mais

eficaz do ponto de vista da resistência e também uma solução mais económica

e simples. Simultaneamente os requisitos deste método viabilizaram e deram

fiabilidade ao produto. Por outro lado, aspetos como a ligação dos componentes

e a conexão correta entre o buzzer, relé e motor de vibração foram outros

pontos que precisaram de ser corrigidos.

Este projeto, para além de ter sido concebido a pensar nas pessoas

portadoras de deficiência auditiva e visual e com dificuldades inerentes à idade

avançada, pode também tirar grande proveito em pessoas que não tenham

qualquer limitação. Para além disso, esta ideia pode gerar funções novas em

oportunidades futuras, como por exemplo no caso de pessoas acamadas com

cuidadores, este sistema poderia, com os devidos ajustamentos, ser utilizado para chamar alguém que está longe, pressionando um botão e o sujeito

cuidador do outro lado recebe o sinal na pulseira. Outo exemplo poderia ser

uma pulseira com imagem e câmara exterior, ou seja, quando alguém tocasse à

campainha, essa câmara deteta a pessoa e encaminha a imagem para a

pulseira, podendo ser vista pelo portador.

O desenvolvimento destas ideias é uma mais-valia da qual a sociedade pode

tirar partido, uma vez que podem ser soluções práticas, simples e,

expectavelmente, económicas. São utilitários com impacto significativo no

quotidiano e na qualidade de vida das pessoas. E é por isso que, acreditamos,

este projeto reúne um conjunto de vantagens que podem ser usufruídas por

todas as pessoas: utilidade, simplicidade, baixo preço, fácil adaptação,

acessibilidade, durabilidade e segurança (não compromete a saúde do

utilizador, que lhe atribuem viabilidade).

### 4. Bibliografia

Baú da Eletrônica Componentes Eletrônicos Ltda. (2014). Sensor de Vibração SW-

420. Obtido de baudaeletronica:

http://www.baudaeletronica.com.br/sensor-de-vibrac-o-sw-420.html

Challenge Electronics. (2010). Omni-Directional Foil Electret Condenser Microphone.

Obtido de Sparkfun:

http://cdn.sparkfun.com/datasheets/Sensors/Sound/CEM-

C9745JAD462P2.54R.pdf

HOLTEK SEMICONDUCTOR INC. (2000). HT12A/HT12E 2^12 Series of Encoders.

Obtido de http://138.197.44.96/datasheets/HT12E.pdf

HOLTEK SEMICONDUCTOR INC. (2002). HT12D/HT12F 2^12 Series of Decoders.

Obtido de http://138.197.44.96/datasheets/HT12D.pdf

Jogando às Cegas. (2015). Jogando às cegas. Obtido de Conheça os tipos de

relógios de pulso para deficientes visuais:

http://jogandoascegas.com.br/relogios-de-pulso-para-deficientes-visuais/

Kushagra. (2012). RF Module (Transmitter & Receiver). Obtido de Engineers

Garage: https://www.engineersgarage.com/electronic-components/rf-

module-transmitter-receiver

Learning About Electronics. (s.d.). learning about electronics. Obtido de How to

Build an Elecret Microphone Circuit:

http://learningaboutelectronics.com/Articles/Electret-microphone-circuit.php

Learning About Electronics. (s.d.). learning about electronics. Obtido de How to

Build a Vibration Motor Circuit:

http://learningaboutelectronics.com/Articles/Vibration-motor-circuit.php

PORDATA. (2015). Indicadores de envelhecimento segundo os Censos - Portugal.

Obtido de Pordata:

http://www.pordata.pt/Portugal/Indicadores+de+envelhecimento+segundo

+os+Censos++-525

PORDATA. (2015). População residente com deficiência segundo os Censos: total e

por tipo de deficiência (1960-2001). Obtido de pordata:

http://www.pordata.pt/DB/Municipios/Ambiente+de+Consulta/Tabela

PRODUZA S/A. (2016). Produza. Obtido de Pré-requisitos técnicos para montar um

projeto eletrônico: http://produza.ind.br/gestao/pre-requisitos-tecnicos-

para-montar-um-projeto-eletronico/

Proto-PIC Electronic Components, RelChron Ltd. (2017). Proto Pic. Obtido de

Electret Microphone: https://www.proto-pic.co.uk/electret-microphone.html

RF Digital . (2015). Simblee™ Bluetooth® Smart Module RFD77101: DATASHEET.

Obtido de Simblee:

https://www.simblee.com/Simblee%20RFD77101%20Datasheet%20v1.0.pd

f

RFduino. (2017). Endless Possibilities For Your Projects. Obtido de Rfduino:

http://www.rfduino.com/

Robokits India. (2017). Robokits. Obtido de HT12E & HT12D Encoder And Decoder

Ic For Rf Modules: http://robokits.co.in/wireless-solutions/ht12e-ht12d-

encoder-and-decoder-ic-for-rf-modules

Santos, D. M. (2017). Relê. Obtido de Infoescola:

http://www.infoescola.com/eletronica/rele/

SparkFun Electronics. (s.d.). RFduino - Simblee Starter Kit. Obtido de Sparkfun:

https://www.sparkfun.com/products/13785

SparkFun Electronics. (s.d.). Vibration Motor. Obtido de Sparkfun:

https://www.sparkfun.com/products/8449

TechTarget. (2017). radio frequency (RF, rf). Obtido de Search Networking:

http://searchnetworking.techtarget.com/definition/radio-frequency

Texas Instruments Incorporated. (2017). ULN2803A Darlington Transistor Arrays.

Obtido de Texas Instruments:

http://www.ti.com/lit/ds/symlink/uln2803a.pdf

Usina. (s.d.). Pulseira Antiestática sem fio para proteção ESD. Obtido de Usinainfo:

http://www.usinainfo.com.br/pulseira-antiestatica/pulseira-anti-estatica-

sem-fio-para-protecao-esd-862.html

Wenshing. (s.d.). Wireless Hi Power Transmitter Module (RF ASK). Obtido de

Cloudfront:

http://dlnmh9ip6v2uc.cloudfront.net/datasheets/Wireless/General/TWS-BS-

3_433.92MHz_ASK_RF_Transmitter_Module_Data_Sheet.pdf

Wenshing. (s.d.). Wireless Hi Sensitivity Receiver Module (RF ASK). Obtido de

Cloudfront:

http://dlnmh9ip6v2uc.cloudfront.net/datasheets/Wireless/General/RWS-

371-6_433.92MHz_ASK_RF_Receiver_Module_Data_Sheet.pdf

Zhejiang Yuesui Electron Stock Co.,Ltd. (2016). Coin Type Vibration Motor . Obtido

de Sparkfun: https://cdn.sparkfun.com/datasheets/Robotics/B1034.FL45-

00-015.pdf

PTRobotics. (s.d.). Buzzer 5V. Obtido de Ptrobotics:

https://www.ptrobotics.com/som/607-buzzer-

5v.html?search_query=buzzer&results=35

PTRobotics. (s.d.). HT12D - Remote Control Decoder. Obtido de Ptrobotics:

https://www.ptrobotics.com/wireless/1200-ht12d-remote-control-

encoder.html?search_query=rf+encoder&results=3

PTRobotics. (s.d.). HT12E - Remote Control Encoder. Obtido de Ptrobotics:

https://www.ptrobotics.com/wireless/1199-ht12e-remote-control-

encoder.html?search_query=rf+encoder&results=3

PTRobotics. (s.d.). RF Link Receiver - 4800bps 434MHz. Obtido de Ptrobotics:

https://www.ptrobotics.com/wireless/877-rf-link-receiver-4800bps-

434mhz.html?search_query=rf+receiver&results=23

PTRobotics. (s.d.). RF Link Transmitter - 434MHz. Obtido de Ptrobotics:

https://www.ptrobotics.com/wireless/875-rf-link-transmitter-

434mhz.html?search_query=rf+transmitter&results=11

PTRobotics. (s.d.). Tactile Button 12mm Black. Obtido de Ptrobotics:

https://www.ptrobotics.com/tactile-switch/1050-tactile-button-12mm-

black.html?search_query=tactile+switch&results=37

PTRobotics. (s.d.). ULN2803. Obtido de Ptrobotics:

https://www.ptrobotics.com/circuitos-integrados-varios/120-

uln2803.html?search_query=uln2803&results=2

PTRobotics. (s.d.). Vibrating Mini Motor Disc. Obtido de Ptrobotics:

https://www.ptrobotics.com/motores-dc/2951-vibrating-mini-motor-

disc.html?search_query=vibration+motor&results=11

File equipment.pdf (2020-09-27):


IMSQUA00805 | Página 1
Aluno: Ricardo Balreira | 12º Ano /Turma I
Material para o projeto | Nº9
Quantidade | Nome | Modelo/referência | Link | Preço Unitário
3 | RF transmitter | PTR000875 | https://www.ptrobotics.com/wireless/875-rf-link-transmitter-434mhz.html?search_query=rf+transmitter&results=11 (https://www.ptrobotics.com/wireless/875-rf-link-transmitter-434mhz.html?search_query=rf+transmitter&results=11) | 4,61 €
3 | RF encoder | PTR001199 | https://www.ptrobotics.com/wireless/1199-ht12e-remote-control-encoder.html?search_query=rf+encoder&results=3 (https://www.ptrobotics.com/wireless/1199-ht12e-remote-control-encoder.html?search_query=rf+encoder&results=3) | 3,69 €
2 | Botão de pressão | PTR001050 | https://www.ptrobotics.com/tactile-switch/1050-tactile-button-12mm-black.html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 (https://www.ptrobotics.com/tactile-switch/1050-tactile-button-12mm-black.html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) | 0,49 €
4 | Resistência de 750k
3 | ULN2803 Circuito Integrado | PTR000120 | https://www.ptrobotics.com/circuitos-integrados-varios/120-uln2803.html | 0,80€
2 | RF receiver | PTR000877 | https://www.ptrobotics.com/wireless/877-rf-link-receiver-4800bps-434mhz.html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 (https://www.ptrobotics.com/wireless/877-rf-link-receiver-4800bps-434mhz.html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) | 5,54 €
4 | Resistência de 33k

IMSQUA00805 | Página 2
2 | RF decoder | PTR001200 | https://www.ptrobotics.com/wireless/1200-ht12d-remote-control-encoder.html?search_query=rf+decoder&results=2 (https://www.ptrobotics.com/wireless/1200-ht12d-remote-control-encoder.html?search_query=rf+decoder&results=2) | 3,69 €
3 | Motor de vibração | PTR002951 | https://www.ptrobotics.com/motores-dc/2951-vibrating-mini-motor-disc.html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 (https://www.ptrobotics.com/motores-dc/2951-vibrating-mini-motor-disc.html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) | 2,77 €
2 | Buzzer | PTR001688 | https://www.ptrobotics.com/som/1688-buzzer-12vdc.html?search_query=buzzer&results=3 6 (https://www.ptrobotics.com/som/1688-buzzer-12vdc.html?search_query=buzzer&results=36) | 3,94 €

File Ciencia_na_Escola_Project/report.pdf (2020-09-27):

Notas: Os anexos ao relatório devem ser enviados pelo correio ou entregues em mão, até ao dia 20 de maio de 2016, dirigidos à Direção de Serviços Regional /Direção Regional de Educação
a. Anexo obrigatório: uma PEN/CD/ DVD contendo uma apresentação, onde estejam bem documentadas, com imagens, as fases e produtos relevantes do projeto desenvolvido (esta apresentação complementará o relatório, na avaliação do projeto).
1. Duração máxima da apresentação: 5 minutos;
2. A PEN/CD/ DVD deverá ser identificada com o nome da Escola, o título do Projeto e o escalão.
b. Anexo(s) facultativo(s): pode(m) ser remetido(s) outro(s) documento(s) ou trabalhos finais que forem considerado(s) relevante(s) para uma boa avaliação do projeto.

RELATÓRIO FINAL DO PROJETO

1. Título do Projeto 300 carateres | BraceletMe
2. Escalão: insira o escalão 2 carateres | 5.º
3. Escola: insira o nome da escola 100 carateres | Escola Secundária Marques de Castilho

### 4. Atividades: descreva as atividades

desenvolvidas
15000 carateres

No âmbito da Prova de Aptidão Profissional, foi proposto elaborar um projeto no contexto de candidatura ao projeto Ciência na Escola da Fundação Ilídio Pinho.
O projeto “BraceletMe” consiste na criação de uma pulseira eletrónica que emite vibração quando a campainha da porta de casa toca, indicando ao portador que se encontra alguém à porta. O projeto parte da consciência de poder contribuir para a solução de alguns problemas do quotidiano das pessoas portadoras de deficiência auditiva e visual e é movido por motivações solidárias. Além disso, poderá ainda ter bastante utilidade no caso de pessoas com limitações inerentes à idade avançada. A ideia surgiu também no facto de existir um familiar próximo com problemas de audição, o que facilita assim a dificuldade em não conseguir ouvir o toque da campainha.

Foram calendarizadas as tarefas relativas à análise do projeto – processo de conceção da pulseira – procedeu-se ao desenho do projeto – pesquisa de soluções e procedimentos para a criação do projeto - e feito o levantamento dos componentes eletrónicos para o desenvolvimento do projeto.

Inicialmente, o protótipo a desenvolver estava em torno da utilização de um mecanismo que permitisse a interação entre o emissor e o recetor através de Bluetooth, o que possibilitava a transmissão de sinal sem fios. O dispositivo a ser implementado tinha como designação de Rfduino, cuja capacidade é poder comunicar à distância, ideal para o funcionamento do projeto.
A primeira abordagem à base do projeto consistia, portanto, em incorporar dois microcontroladores Rfduino que pudessem comunicar entre si. Para que houvesse a receção

Notas: Os anexos ao relatório devem ser enviados pelo correio ou entregues em mão, até ao dia 20 de maio de 2016, dirigidos à Direção de Serviços Regional /Direção Regional de Educação
a. Anexo obrigatório: uma PEN/CD/ DVD contendo uma apresentação, onde estejam bem documentadas, com imagens, as fases e produtos relevantes do projeto desenvolvido (esta apresentação complementará o relatório, na avaliação do projeto).
1. Duração máxima da apresentação: 5 minutos;
2. A PEN/CD/ DVD deverá ser identificada com o nome da Escola, o título do Projeto e o escalão.
b. Anexo(s) facultativo(s): pode(m) ser remetido(s) outro(s) documento(s) ou trabalhos finais que forem considerado(s) relevante(s) para uma boa avaliação do projeto.

RELATÓRIO FINAL DO PROJETO
e passagem do sinal, teria que existir um microfone dentro do circuito.

Prosseguimos então com a solução de utilizar dois Rfduinos fazendo vários ensaios e desenhos no programa “Fritzing” onde é possível construir circuitos elétricos. Procurámos formas de existir receção e passagem do sinal e vibração da pulseira. Consistiam, portanto, em utilizar um microfone para a receção e passagem do sinal e um motor de vibração para a pulseira emitir sinal.

No que respeita ao componente responsável por emitir sinal na pulseira, o elemento que iria assumir essa função seria o motor de vibração.
Depois de termos uma noção dos elementos a utilizar no projeto, prosseguimos para a etapa seguinte, que consistia em procurar e pesquisar formas de instalar cada componente nas condições descritas anteriormente. Através dos esquemas elétricos de ambos os componentes e do
Rfduino, | procurámos | conhecer | o | esquema | do
funcionamento de uma campainha, de forma a determinar maneiras de instalar a estrutura do Rfduino e do microfone na campainha, uma vez que o motor de vibração irá estar na pulseira.

Para montar um microfone do tipo eletreto (cuja finalidade é servir de escuta) vai ser preciso utilizar uma resistência de 2.2KΩ e um condensador eletrolítico de 100µF. Como também será necessário interligar a uma ficha de áudio e assim conectar a um computador. Chegámos à conclusão que não era, de certo modo, vantajoso optar por este elemento, dado que este circuito exigia demasiada
complexidade, | segundo | os | tutoriais | vídeo | que
demonstravam, passo a passo, a montagem.
Partindo do pressuposto que a nossa “BraceletMe” estaria conectada a uma campainha de residência, estudámos o esquema elétrico respetivo. Procedemos também ao desenho do esquema do microfone no programa “Fritzing”

Notas: Os anexos ao relatório devem ser enviados pelo correio ou entregues em mão, até ao dia 20 de maio de 2016, dirigidos à Direção de Serviços Regional /Direção Regional de Educação
a. Anexo obrigatório: uma PEN/CD/ DVD contendo uma apresentação, onde estejam bem documentadas, com imagens, as fases e produtos relevantes do projeto desenvolvido (esta apresentação complementará o relatório, na avaliação do projeto).
1. Duração máxima da apresentação: 5 minutos;
2. A PEN/CD/ DVD deverá ser identificada com o nome da Escola, o título do Projeto e o escalão.
b. Anexo(s) facultativo(s): pode(m) ser remetido(s) outro(s) documento(s) ou trabalhos finais que forem considerado(s) relevante(s) para uma boa avaliação do projeto.

RELATÓRIO FINAL DO PROJETO
para nos auxiliar na montagem do protótipo. Por outro lado, pesquisámos um esquema elétrico que possibilitasse a vibração da pulseira através de um motor de vibração e complementámo-lo com outro esquema no programa “Fritzing” de modo a poder recriar essa funcionalidade no protótipo.

De modo a possibilitar a simulação do circuito, sem ter que recorrer a uma campainha de uma casa, surgiu a hipótese de utilizar uma componente que emitisse um som semelhante a uma campainha. Foi utilizado, então, um buzzer, dispositivo que envia sinal sonoro, para substituir a
função | da | campainha. | Seguindo | alguns | tutoriais,
operacionalizou-se a simulação, no Fritzing, do buzzer e outros elementos necessários, como o botão de pressão, o motor de vibração, a resistência de 330Ω, a pilha de 9V e a protoboard.

O buzzer está ligado ao botão de pressão e este está ligado ao motor de vibração, com uma resistência ligada ao terminal positivo. Desta forma, assim que é pressionado o botão de pressão, o buzzer e o motor de vibração são ativados.
No entanto, após algumas pesquisas e discussão entre a professora orientadora e os orientandos, inferiu-se que não era possível continuar com este método de resolução do problema, uma vez que dois Rfduinos não conseguem interagir um com o outro. O Rfduino foi apenas desenvolvido para comunicar com tablet ou telemóvel.

No fórum online do Rfduino, onde diversas pessoas podem esclarecer dúvidas com especialistas, o administrador afirmou que não é possível interligar um com o outro, referindo que este tipo de microcontrolador é um periférico, apenas utilizado para dispositivos móveis que utilizam Bluetooth.

Assim, procurámos outros procedimentos e soluções para

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

RELATÓRIO FINAL DO PROJETO
resolver esta questão. Surgiu a ideia de utilizar o mesmo mecanismo usado nos automóveis para o controlo remoto.

Decidimo-nos por uma solução que permite a comunicação à distância. Essa solução consistia em utilizar um transmissor e um recetor comunicando através de radiofrequência (RF).

Esta técnica consiste em utilizar o módulo RF (“transmitter” e “receiver”) e dois RF “encoder” e “decoder”, sendo os elementos principais da montagem. O RF transmitter é uma placa de circuito impresso que recebe dados em série e transmite-os, sem necessitar de conexão de fios, através da sua antena conectada no pino 4. O RF receiver recebe os dados transmitidos por este componente que opera à mesma frequência que o RF transmitter. Os RF encoder e decoder utilizam-se na ligação de controlo remoto RF, assegurando e tornando mais fiável essa mesma ligação, sendo bastante fácil incorporá-los no RF module (módulo RF), sendo facilmente integrados. Tal como os nomes indicam, encoder e decoder significam “codificar” e “descodificar”, respetivamente. Como esta solução foi baseada num vídeo que vimos durante a pesquisa por uma nova solução, foi preciso estudar o circuito, cada componente e consultando o datasheet de cada componente (ficha técnica) e a ligação dos terminais e pinos, de forma a retirar os LED e substitui-los pelo buzzer e motor de vibração, deixando apenas um botão de pressão no emissor.

Encontrada a solução para assegurar a funcionalidade do esquema do nosso projeto, procedemos à aquisição das duas componentes essenciais: RF transmitter e o RF receiver. Os microcontroladores encoder e decoder obedecem a um esquema específico de pinos que é necessário ter em conta para estabelecer a ligação entre estes dois componente e outros, como por exemplo, botão de pressão, resistência e buzzer. Definidos os elementos a utilizar, prosseguimos então para a etapa seguinte que

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

RELATÓRIO FINAL DO PROJETO
consistia em pedir o material para assim construir o protótipo. Durante o período de montagem do circuito surgiram alguns contratempos. O facto de a ligação dos componentes e do facto do motor de vibração estar acionado constantemente, sem sequer existir um mecanismo que o ligasse e desligasse, foi um dos aspetos a corrigir nesta fase.

Após a ligação entre os circuitos estar a funcionar, foi preciso optar por uma alternativa que ligasse e desligasse o motor de vibração e buzzer consoante o pressionar do botão de pressão. Essa alternativa consistiu em utilizar um componente denominado de relé. O relé é um componente eletromecânico que permite ligar e desligar um sinal, ou seja, é constituído por um mecanismo que bloqueia e desbloqueia o sinal percorrido. Um relé é composto por uma bobina e por um grupo de contactos. Esses contactos têm
como | designação | Normalmente | Fechado | (NF) | e
Normalmente Aberto (NA), existindo um terceiro contacto (Contacto Comum) que está situado entre ambos. Quando não há passagem de energia na bobina, o contacto comum está conectado ao NF com o contacto NA aberto. Quando há passagem de corrente, a bobina cria um campo magnético que vai permitir deslocar o contacto comum ligando-se assim ao contacto NA, através de uma mola.

No decorrer das montagens, notou-se que era preciso um microcontrolador que permitisse conduzir a corrente até ao relé para que este ativasse e acionasse o motor de vibração. Sem isso, não é possível a passagem de corrente até ao relé. Neste caso foi necessário introduzir uma outra componente, circuito integrado ULN2803, que garante a passagem de corrente.

Até à fase da conclusão do circuito, foi necessário repetir várias vezes a montagem até termos o resultado desejado, tentando corrigir os problemas de mau contacto, falha nas ligações e falta ou excesso de passagem de corrente. Vários

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

RELATÓRIO FINAL DO PROJETO
problemas que surgiram ao longo do trabalho tiveram que ser analisados para assim serem emendados. Utilizaram-se transístores para transformar a tensão da pilha de 9V em 5V, uma vez que não tínhamos disponíveis pilhas de voltagem mais baixa. Os transístores cingiram-se apenas para o motivo referido e para teste, em ambos os circuitos.

### 5. Grau de experimentação do projeto:

enumere as atividades experimentais, laboratoriais ou de campo realizadas com os alunos.
4000 carateres

A primeira abordagem à base do projeto consistia, portanto, em incorporar dois microcontroladores Rfduino que pudessem comunicar entre si. Para que houvesse a receção e passagem do sinal, teria que existir um microfone dentro do circuito.

No que respeita ao componente responsável por emitir sinal na pulseira, o elemento que iria assumir essa função seria o motor de vibração.

Depois de termos uma noção dos elementos a utilizar no projeto, prosseguimos para a etapa seguinte, que consistia em procurar e pesquisar formas de instalar cada componente nas condições descritas anteriormente. Através dos esquemas elétricos de ambos os componentes e do
Rfduino, | procurámos | conhecer | o | esquema | do
funcionamento de uma campainha, de forma a determinar maneiras de instalar a estrutura do Rfduino e do microfone na campainha, uma vez que o motor de vibração irá estar na pulseira.

Para montar um microfone do tipo eletreto (cuja finalidade é servir de escuta) vai ser preciso utilizar uma resistência de 2.2KΩ e um condensador eletrolítico de 100µF. Como também será necessário interligar a uma ficha de áudio e assim conectar a um computador. Chegámos à conclusão que não era, de certo modo, vantajoso optar por este elemento, dado que este circuito exigia demasiada
complexidade, | segundo | os | tutoriais | vídeo | que
demonstravam, passo a passo, a montagem.

Partindo do pressuposto que a nossa “BraceletMe” estaria conectada a uma campainha de residência, estudámos o

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

RELATÓRIO FINAL DO PROJETO
esquema elétrico respetivo. Procedemos também ao desenho do esquema do microfone no programa “Fritzing” para nos auxiliar na montagem do protótipo. Por outro lado, pesquisámos um esquema elétrico que possibilitasse a vibração da pulseira através de um motor de vibração (Fig.
10) e complementámo-lo com outro esquema no programa “Fritzing” de modo a poder recriar essa funcionalidade no protótipo. Finalmente, a ilustra a junção das duas componentes: o emissor (esquema do microfone) e o recetor (esquema do motor de vibração).

De modo a possibilitar a simulação do circuito, sem ter que recorrer a uma campainha de uma casa, surgiu a hipótese de utilizar uma componente que emitisse um som semelhante a uma campainha. Foi utilizado, então, um buzzer, dispositivo que envia sinal sonoro, para substituir a função da campainha. Seguindo alguns tutoriais, operacionalizou-se a simulação, no Fritzing, do buzzer e outros elementos necessários, como o botão de pressão, o motor de vibração, a resistência de 330Ω, a pilha de 9V e a protoboard.

O buzzer está ligado ao botão de pressão e este está ligado ao motor de vibração, com uma resistência ligada ao terminal positivo. Desta forma, assim que é pressionado o botão de pressão, o buzzer e o motor de vibração são ativados.
No entanto, após algumas pesquisas e discussão entre a professora orientadora e os orientandos, inferiu-se que não era possível continuar com este método de resolução do problema, uma vez que dois Rfduinos não conseguem interagir um com o outro. O Rfduino foi apenas desenvolvido para comunicar com tablet ou telemóvel.

No fórum online do Rfduino, onde diversas pessoas podem esclarecer dúvidas com especialistas, o administrador afirmou que não é possível interligar um com o outro, referindo que este tipo de microcontrolador é um periférico, apenas utilizado para dispositivos móveis que utilizam Bluetooth; no entanto, ele diz ainda que essa funcionalidade

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

RELATÓRIO FINAL DO PROJETO
já está a ser desenvolvida, estando em estudo a utilização de mecanismos de radiofrequência (emissor – recetor) – RF library.
Assim, procurámos outros procedimentos e soluções para resolver esta questão. Surgiu a ideia de utilizar o mesmo mecanismo usado nos automóveis para o controlo remoto.

Decidimo-nos por uma solução bastante eficaz e simples que permite a comunicação à distância. Essa solução consistia em utilizar um transmissor e um recetor comunicando através de radiofrequência (RF).

Esta técnica consiste em utilizar o módulo RF (“transmitter” e “receiver”) e dois RF “encoder” e “decoder”, sendo os elementos principais da montagem.

Como o autor do vídeo que nos baseamos utilizou o circuito para outra finalidade – ligar vários díodos LED alternadamente – foi preciso estudar o circuito, cada componente e consultando o datasheet de cada componente (ficha técnica) e a ligação dos terminais e pinos, de forma a retirar os LED e substitui-los pelo buzzer e motor de vibração, deixando apenas um botão de pressão no emissor.

Encontrada a solução para assegurar a funcionalidade do esquema do nosso projeto, procedemos à aquisição das duas componentes essenciais: RF transmitter e o RF receiver.

Os microcontroladores encoder e decoder obedecem a um esquema específico de pinos que é necessário ter em conta para estabelecer a ligação entre este componente e outros, como por exemplo, botão de pressão, resistência e buzzer, tal como é ilustrado na, mais à frente neste relatório.

Definidos os elementos a utilizar, prosseguimos então para a etapa seguinte que consistia em pedir o material para assim construir o protótipo. Durante o período de montagem do

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

RELATÓRIO FINAL DO PROJETO
circuito surgiram alguns contratempos. O facto de a ligação dos componentes e do facto do motor de vibração estar acionado constantemente, sem sequer existir um mecanismo que o ligasse e desligasse, foi um dos aspetos a corrigir nesta fase.

Após a ligação entre os circuitos estar a funcionar, foi preciso optar por uma alternativa que ligasse e desligasse o motor de vibração e buzzer consoante o pressionar do botão de pressão. Essa alternativa consistiu em utilizar um componente denominado de relé.

No decorrer das montagens, notou-se que era preciso um microcontrolador que permitisse conduzir a corrente até ao relé para que este ativasse e acionasse o motor de vibração. Sem isso, não é possível a passagem de corrente até ao relé. Neste caso foi necessário introduzir uma outra componente, circuito integrado ULN2803, que garante a passagem de corrente, onde é esquematizado os pinos de ligação.

### 6. Relevância: indique a relevância científico-

pedagógica do projeto para os alunos e para a comunidade educativa.
3000 carateres

De um modo geral, este projeto pode ter grande relevância nos alunos pois incentiva muitos deles a dar asas à imaginação e a porem em prática as suas ideias que podem vir a ter um grande potencial. Essas ideias podem ser demasiado simples, mas se forem bem desenvolvidas podem tornar-se numa necessidade universal tirando grande proveito da sua potencialidade. Este protótipo poderá ainda ter bastante utilidade no caso de pessoas com limitações inerentes à idade avançada. De acordo com a base de dados da PORDATA, o índice de envelhecimento e de dependência de idosos aumentou progressivamente em 50 anos. À medida que uma pessoa atinge uma idade avançada, os seus sentidos (audição e/ou visão) ficam mais enfraquecidos. Desta forma, poderá ser uma grande vantagem para idosos com dificuldade em ouvir.

7. Inovação: refira aspetos inovadores, criativos ou de possível utilidade empresarial do projeto
4000 carateres

Consideramos que este projeto é inovador porque concebe um produto novo combinando componentes electrónicos já existentes e de baixo custo.
O mecanismo de protótipo resultante deste projeto pode

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

RELATÓRIO FINAL DO PROJETO
tornar-se um produto a experimentar primeiramente no seio da comunidade com dificuldade em ouvir e inerentes à idade avançada, permitindo a diminuição dos problemas do quotidiano. Deste projecto, podem surgir outras ideias semelhantes com o objectivo de facilitar o dia-a-dia do utilizador. O facto de ser simples e concebido numa necessidade básica, pode ser uma mais-valia para as empresas.

### 8. Parceria (s): indique a(s) parceria(s)

estabelecida(s) com instituições externas à escola, indicando o nome da(s) entidade(s) e o(s) contributo(s) para o
desenvolvimento do projeto.
3000 carateres

Foram estabelecidas as seguintes parcerias:
1- Águeda Living Lab (espaço aberto à comunidade para o encontro de ideias, experiências, conhecimento, criatividade e inovação de Águeda): parceiros na dinamização de um workshop usando o programa Blender onde os alunos aprenderam as noções básicas de modelação 3D, com o objetivo de desenvolver um suporte para o protótipo e posterior impressão 3D; e na disponibilização do makerspace e recursos disponíveis.

### 9. Resultados: refira os resultados obtidos

(nas aprendizagens dos alunos, na comunidade educativa e nas instituições com que estabeleceu parcerias)
3000 carateres

Este projeto insere-se na linha estratégica do Projeto Educativo Projeto Educativo AEAS 2013-17, nomeadamente nos seguintes objetivos estratégicos: aposta em modelos de ensino e aprendizagem focalizados no desenvolvimento de capacidades, assente em pedagogias diferenciadas e inovadoras que valorizem o ensino experimental das ciências e as TIC; aprofundamento e consolidação da cooperação com o tecido social e empresarial, com o poder local e com a universidade, com vista à integração plena dos alunos na vida ativa, ao desenvolvimento do gosto pela ciência, pela investigação e pela inovação e ao alargamento dos horizontes de emprego; e realização de cursos avançados, ou de aprofundamento, destinados a alunos do 9º ano e do ensino secundário e a professores, com recurso a parcerias com instituições ligadas à investigação e à promoção da educação para a ciência.
Assim, devidamente enquadrado na visão do Projeto Educativo, este projeto proporcionou aos alunos a possibilidade de desenvolverem competências ao nível do uso e aplicação de conhecimentos e metodologias para encontrarem soluções para problemas do mundo real. Além disso, os alunos promoveram a capacidade de passar das

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

RELATÓRIO FINAL DO PROJETO
ideias aos atos, através de processos de criatividade e a inovação, da assunção de riscos, bem como a capacidade de planear e gerir projetos para alcançar objetivos. Foram capazes de aproveitar esta oportunidade transformando-a em aprendizagem e desenvolvimento técnico na área das soluções pensadas informaticamente e com recurso à tecnologia eletrónica.

Além disso, desenvolveram capacidades de iniciativa na gestão de projetos e equipas; aptidão e gosto por uma aprendizagem contínua, prática na aplicação de modelos de desenho e de metodologias no âmbito de programação, experiência na realização de trabalho colaborativo; Interpretação e representação de esquemas elétricos e eletrónicos, e de identificação, medição e testagem componentes eletrónicos ….
Relativamente à comunidade educativa foram realizadas algumas apresentações no dia Aberto e nas Jornadas Técnicas da escola nos dias 3, 4 e 5 de maio, tendo despertado interesse por parte dos alunos.

Contactaram-se as empresas Feiramédica, Lenadais e Aveimédica, pertencentes ao distrito de Aveiro, ligadas à
geriatria | ou | saúde | para | poderem | contribuir | na
exequibilidade do projecto.

### 10. Informação complementar: refira outras

informações consideradas pertinentes 6000 carateres

Este projeto, para além de ter sido concebido a pensar nas pessoas portadoras de deficiência auditiva e visual e com dificuldades inerentes à idade avançada, pode também tirar grande proveito em pessoas que não tenham qualquer limitação. Para além disso, esta ideia pode gerar funções novas em oportunidades futuras, como por exemplo no caso de pessoas acamadas com cuidadores, este sistema poderia, com as devidos ajustamentos, ser utilizado para chamar alguém que está longe, pressionando um botão e o sujeito cuidador do outro lado recebe o sinal na pulseira. Outo exemplo poderia ser uma pulseira com imagem e câmara exterior, ou seja, quando alguém tocasse à campainha, essa câmara deteta a pessoa e encaminha a imagem para a

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

RELATÓRIO FINAL DO PROJETO pulseira, podendo ser vista pelo portador.

11. Lista nominal dos alunos participantes no projeto (primeiro e último nome/ano) 3000 carateres | Andriy Horshynskyy – 12.ºI Ricardo Balreira – 12.ºI
12. Lista nominal dos professores colaboradores no projeto (primeiro e último nome/grupo disciplinar) 3000 carateres | Ana Cristina Marques – Grupo 550 - Informática Nazaré Freitas – Grupo 550 - Informática Daniela Ferreira – Grupo 550 - Informática

### 13. Resumo do projeto

200 carateres

Este trabalho visa explorar mecanismos que permitem a transmissão de sinal de radiofrequência, possibilitando a interação entre uma campainha (emissor) e uma pulseira (recetor), com recurso ao processo de comunicação com ondas de radiofrequência, uma vez que reúne o conjunto de características ideais para o seu funcionamento e comportam grandes distâncias.
O projeto “BraceletMe” consiste na criação de um protótipo de pulseira electrónica conectada à campainha de uma porta de residência, permitindo que sempre que a campainha toca, um sinal é emitido para a pulseira, indicando ao portador da pulseira que está alguém à porta. Com ajuda da transmissão de radiofrequência vai ser possível criar uma ligação entre a pulseira (emissor) e a campainha (recetor). A pulseira tem um motor capaz de vibrar que indica à pessoa quando está alguém a tocar à campainha.

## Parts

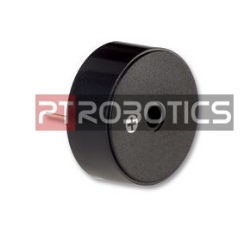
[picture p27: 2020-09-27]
components/Buzzer.PNG

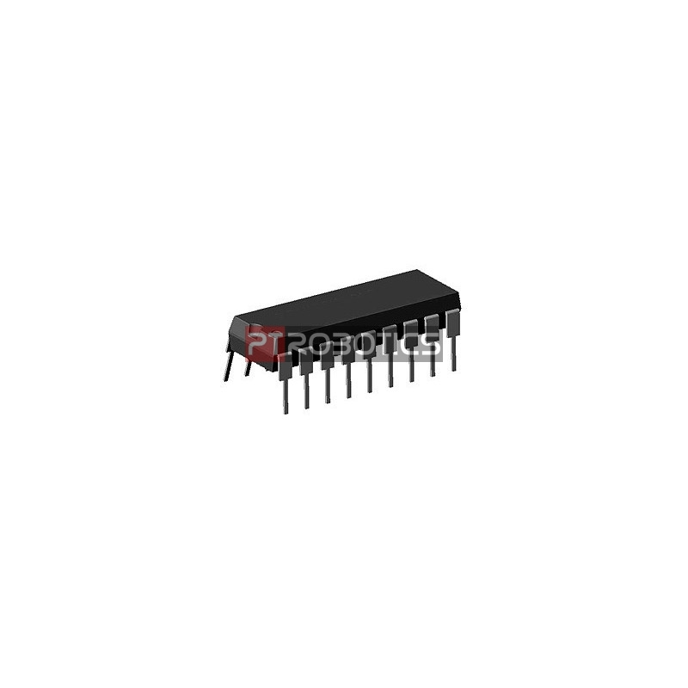
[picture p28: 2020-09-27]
components/ULN2803.jpg

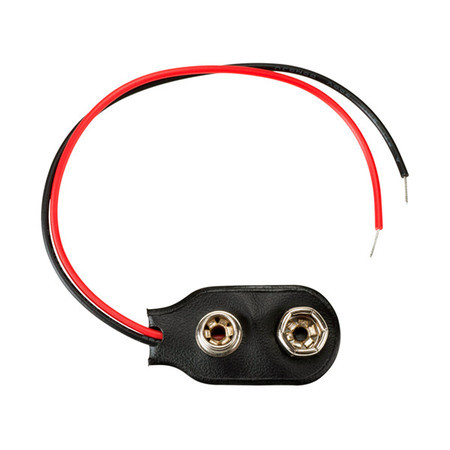
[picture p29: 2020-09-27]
components/battery_support.jpg

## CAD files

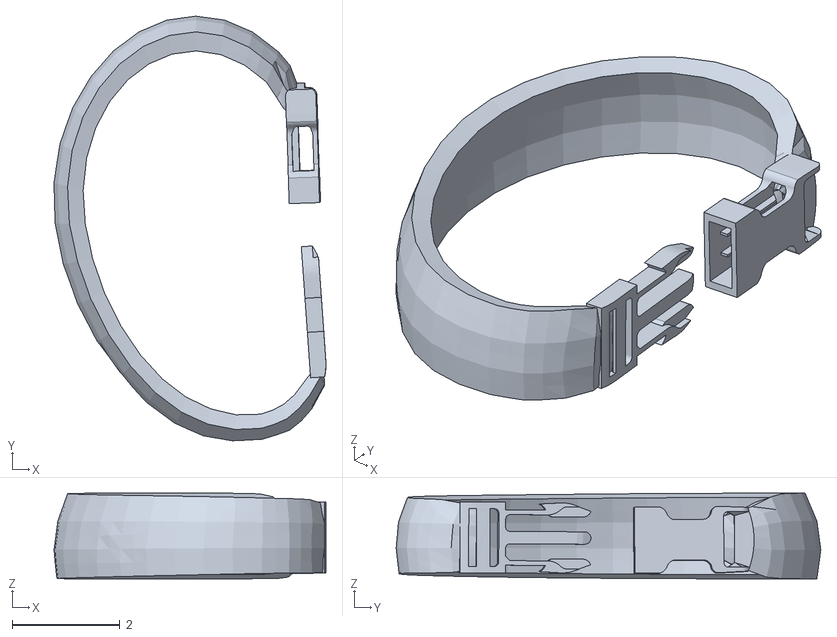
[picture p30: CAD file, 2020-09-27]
bracelet_3d.stl
5.04 x 7.87 x 1.59

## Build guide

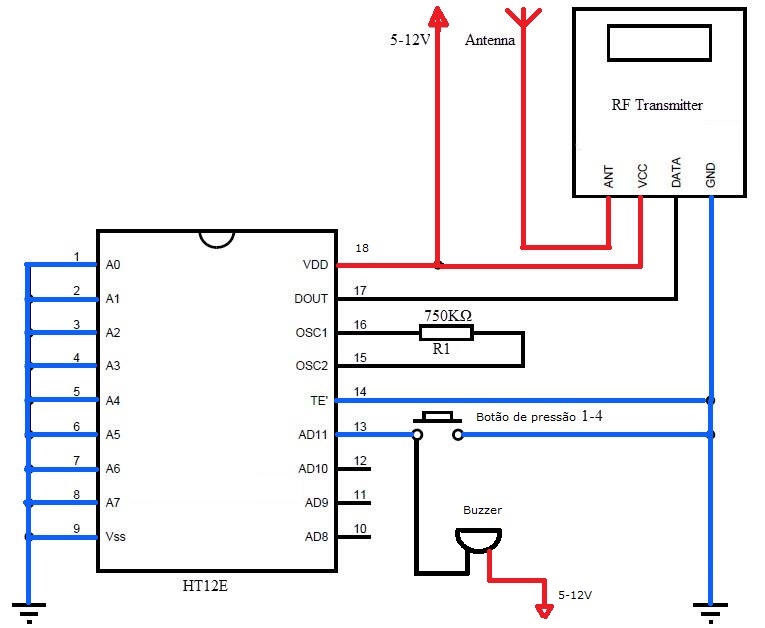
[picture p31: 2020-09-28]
assembly_pictures/schema/transmitter_schema.jpg
